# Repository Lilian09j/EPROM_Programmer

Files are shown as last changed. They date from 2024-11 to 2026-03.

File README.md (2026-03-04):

# EPROM_Programmer
EPROM programmer (reading and writing operations) for 27C512 and 27C64 UV and EEPROMs.

Provide a manual programmation through Dip switchs as well as a microprogrammed one based on a STM32F103. A MAX734 is used to generate the 12v tension needed for programming. PCB conception made on Altium Designer. A JAVA app were developed to communicate buy USB with the PIC microcontroller allowing reading and programming.

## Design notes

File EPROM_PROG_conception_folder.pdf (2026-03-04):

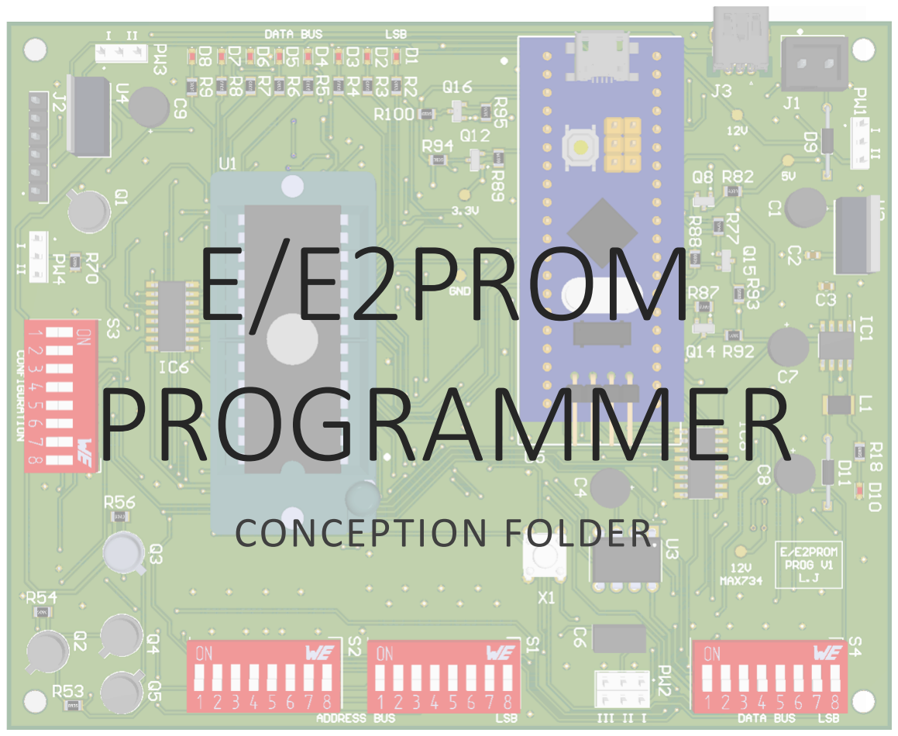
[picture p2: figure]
E/E2PROM PROGRAMMER; CONCEPTION FOLDER

E/E2PROM PROGRAMMER | 1 | L.J
JAOUANNE Lilian | 07-2025

E/E2PROM PROGRAMMER | 2 | L.J

## Table des matières

E/E2PROM PROGRAMMER | 3 | L.J

## Introduction

The E/E2PROM PROG board is used to read and program UV-EPROM (Erasable Programmable Read-Only Memory) and (Electrical Erasable) EEPROM non volatile memories with a maximum of 64kB.
The memory bytes can be read or written either manually via DIP switches (manual mode) or through a Java-based GUI application running on a laptop. The application communicates with the STM32F103 microcontroller on the board via USB, which operates as a Virtual COM Port (VCP). Mode selection is done using jumpers on the board.

The EPROM component must be in an FDIP28 (28 pin Ceramic Frit-seal DIP) or FDIP28W package, with FDIP28W indicating the presence of a quartz window on top of the case, which allows the memory to be erased using ultraviolet (UV) light.

When delivered (and after each erasure for UV EPROM), all bits of the M27C512 are in the '1' state. Data is introduced by selectively programming '0's into the desired bit locations. Although only '0's will be programmed, both '1's and '0's can be present in the data word. The only way to change a '0' to a '1' is by die exposure to ultraviolet light (UV EPROM).
The M27C512 begins to erase when exposed to light with wavelengths below 400 nm (4000 Å
- angstrom). Direct sunlight can cause erasure in about one week. The recommended method is UV-C exposure at 2537 Å (253.7 nm) for faster, controlled erasure.

The integrated dose (i.e. UV intensity × exposure time) for erasure should be a minimum of 15 W. sec. cm² or J. cm⁻²
e.g. : Erasure time of 20min using an UV lamp with 12000µW. cm⁻² power rating.
- The UV-EPROM 27C512 (512 kbits) has 16 addresses bits so 2

16 = 65536
addressable 8-bit memory area.

2

16 × 8bits = 2

16 × 2

−10 × 8kbits = 2

6 × 2

3kbits = 512kbis = 64kB

Thus, the memory can be represented by 4096 (2

16/16) lines of 16 bytes. The range of addresses of the lines would be 0x0000 to 0xFFF0 (2

16 − 16 bytes) as well the last address byte is 0xFFFF.

- However the EEPROM 28C64 (64 kbits) has only a 13 addresses bits so 2

13 = 8192
addressable 8-bit memory area.

2

13 × 8bits = 2

13 × 2

−10 × 8kbits = 2

3 × 2

3kbits = 64kbis = 8kB

Thus, the memory can be represented by 512 (2

13/16) lines of 16 bytes. The range of addresses of the lines would be 0x000 to 0x1F0 (2

13 − 16 bytes) as well the last address byte is 0x1FF.

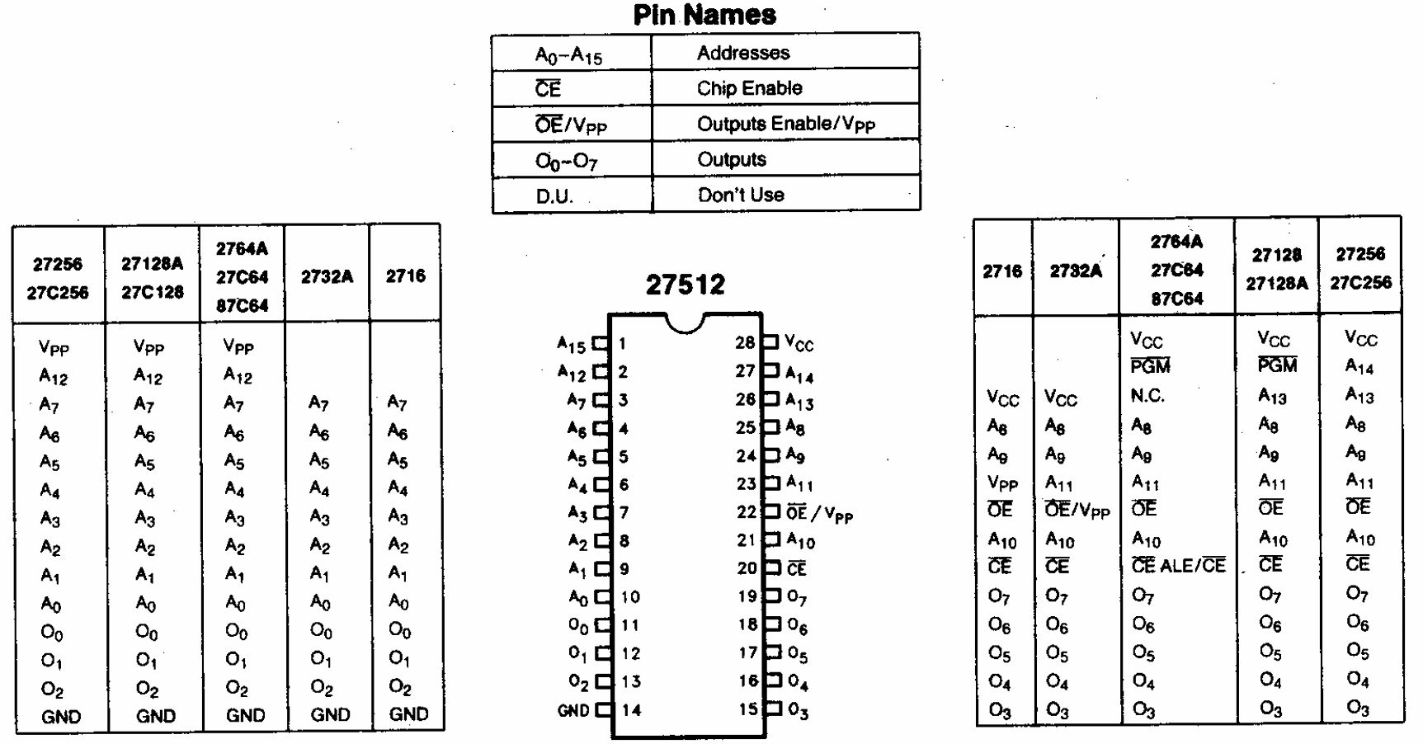
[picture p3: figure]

E/E2PROM PROGRAMMER | 4 | L.J

## I. EPROM mode details

## Pinout

The 28C64 EEPROM’s pinout has some differences with the 27C512 one :

A13 : NC, A14 : PGM also called write enable WE for 28C64, A15 : Ready/Busy Output 10K resistor as A15 can be an output (28C64) or an input (27C512).

Figure 1 : 27C512 – 27C64 pinout

The modes of operations of the 27C512 are listed in the Operating Modes table (Cf. Table 1). All inputs are TTL levels except for OE/Vpp and 12v on A9 for Electronic Signature.

Table 1 : 27C512 operating modes
Mode | Vcc | CE | OE/Vpp | A9 | Q7 − Q0
Read | 5v | VIL | VIL | X | Data Out
Output disable | 5v | VIL | VIH | X | Hi-Z
Program | 6v | VIL pulse | Vpp | X | Data In
Verify | 6v | VIL | VIL | X | Data Out
Program Inhibit | 6v | VIL | Vpp | X | Hi-Z
Standby | 5v | VIH | X | X | Hi-Z
Electronic Signature | 5v | VIL | VIL | VID | Codes IDs

X = VIH (5v) or VIL(0v) , Vpp = 12,75v ± 0,25v (if M27C512) , Vpp = 12,5v ± 0,5v (if D27C512), VID = 12v ± 0,5v

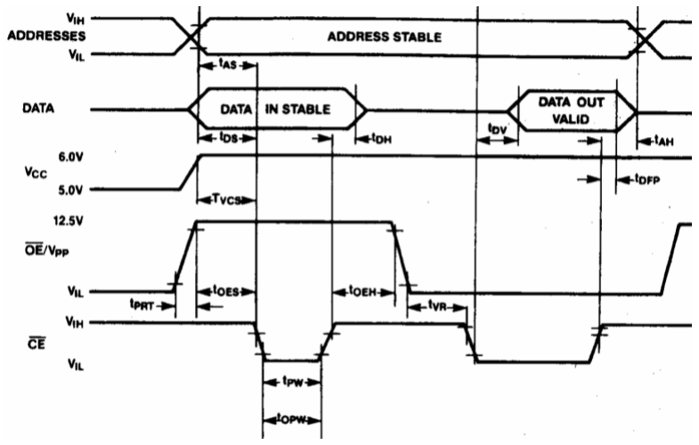
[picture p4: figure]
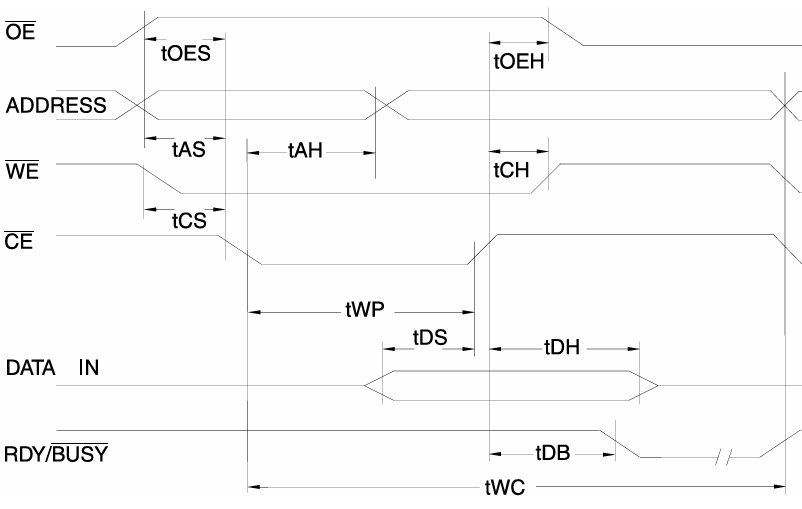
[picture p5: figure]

E/E2PROM PROGRAMMER | 5 | L.J

However after tests the writing mode is still working with Vpp under 12v. As well we can take it after the diode in series with the 12v source.

## Reading mode

The 27C512 has 2 control functions, both of which must be logically active in order to obtain data at the outputs. Chip Enable (CE) is the power control and should be used for device selection. Output Enable (OE/Vpp) is the output control and should be used to gate data from the output pins, independent of device selection.

## Writing/programming mode

Figure 2 : EPROM (D27C512) programming waveform | Figure 3 : EPROM (28C64) programming waveform \C\E controlled

The time characteristics are provided in the datasheets.

A verify (read) should be performed on the programmed bits to determine that they have been correctly programmed. The verify is performed with OE/Vpp and CE at VIL and Vcc is at its programming voltage (6v).

The 28C64’s pin 1 is READY/BUSY (not A15 as for the 27C512). It has an open drain output that can be used to detect the end of a write cycle. READY/BUSY is actively pulled low during the write cycle and is released at the completion of the write. The open drain connection allows for OR-tying of several devices to the same READY/BUSY line.

Remark : The READY/BUSY is not connected for the AT28C64X.

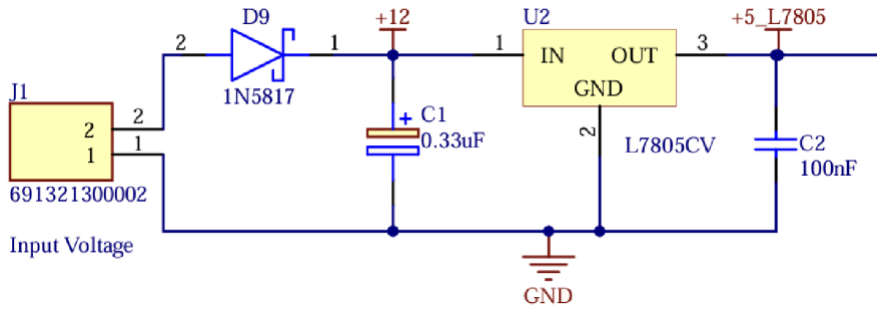
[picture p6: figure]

E/E2PROM PROGRAMMER | 6 | L.J

## II. Board power supply

The board requires a 12v power supply. This 12v generates a 5v voltage by a linear regulation. The L7805CV is a three-terminal 5v positive regulators in a TO-220 package. It can provide a maximum output current of 1,5A.

Power Dissipation Without Heatsink :

TJmax = 125°C (junction temperature, temperature inside the silicon die of the chip)

RθJA = 65°C/W (thermal resistance from junction to ambient)

Pmax =

TJmax − Tambient

RθJA

=

125 − 25
65 ≈ 1,54W

Thus, without a heatsink, the L7805CV can safely dissipate 1,5W.

The input decoupling capacitor C1 stabilizes the input voltage, especially if it is noisy or coming from a long wire or switch-mode supply to prevents oscillations in the regulator. It is required if the regulator is located far from the power source.

The output decoupling capacitor C2 improves the transient response, high-frequency noise and helps smooth out voltage changes due to load variations.

A Schottky diode (metal-semiconductor junction) in series with the input is used to block reverse voltage, preventing damage. It has a lower forward voltage drop: ~0.3 − 0.4 V (vs. ~0.7 V for standard diodes in Silicon with an PN junction).

Remark : Even if the L7805 can accept an input until 35v, the input voltage must be 12v ± 0,5v in this application, as the 12v source is also used for the EPROM OE for programming purposes.

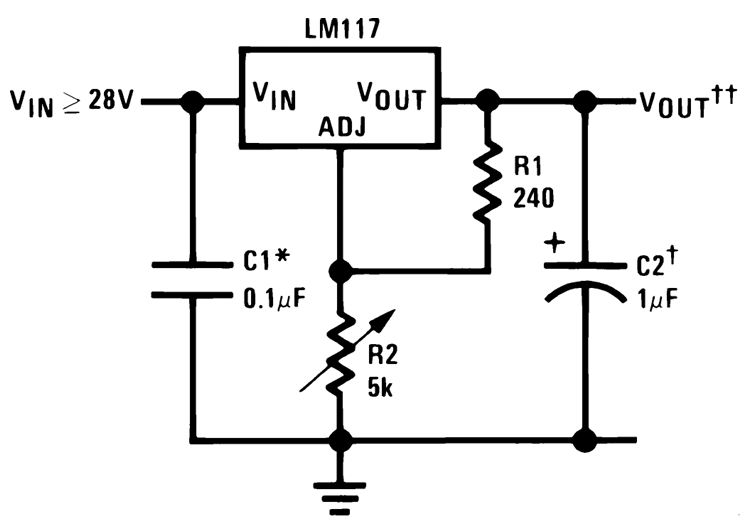
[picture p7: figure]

E/E2PROM PROGRAMMER | 7 | L.J

## III. EPROM 5v/6v power supply

The EPROM requires a 5v power supply in reading mode and 6v in writing on the pin Vcc (28).

Figure 4 : LM317 basic schematic from datasheet
Computing the output voltage (Vout) of an LM317 1.2-37v adjustable regulator (from an input at least 3v over the desired output) is done using the following formula (Eq. XIII.1) :

Vout = 1.25 × (1 +

R2
R1

)

R1 and R2 are the values of the trimmer resistors. In practice, one usually chooses a value for R1 (often 220 or 240 ohms) and calculates the value of R2 needed to obtain the desired output voltage.

The LM317's internal reference voltage is 1.25V. This voltage is always present between the ADJ pin and the OUT pin.

- Vout = 6v with R1 = 220Ω :
R2 = (
Vout

Vref

− 1) × R1 =
6 − 1,25
1,25 × 220 = 830Ω (we will take R2 = 820Ω)

R2 × IADJ ≈ 820 × 50.10⁻⁶ = 4,1mV (negligible)

- Vout = 5v with R1 = 220Ω :

R2 =

5 − 1,25
1,25 × 220 = 660Ω

Let R2 and R3 be 2 resistors in parallel, we want R3 such as Req ≈ 660Ω.

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
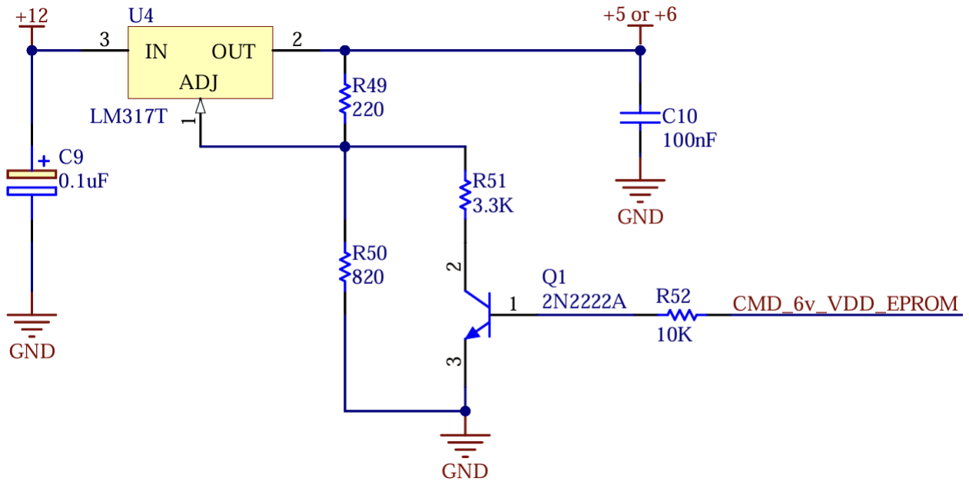
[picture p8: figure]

E/E2PROM PROGRAMMER | 8 | L.J

R3 =

Req × R2
R2 − Req

=

660 × 820
820 − 660 ≈ 3,38kΩ (we will take R3 = 3, 3kΩ)

Figure 5 : 5 or 6v regulation diagram with LM317 for EPROM power supply

- NPN Q1 transistor blocked if CMD_6v_VDD_EPROM Low : Vout ≈ 1,25 (1 +

820
220) = 5,91v
- NPN Q1 transistor passing (saturated) if CMD_6v_VDD_EPROM High :

Req =

820 × 3,3.10³
820 + 3,3.10³

≈ 657Ω

Vout ≈ 1,25 (1 +

657
220) = 4,98v

Remark : The power switching characteristics of Advanced CMOS EPROMs require careful decoupling of the devices. The supply current ICC has three segments that are of interest to the system designer: the standby current level, the active current level, and transient current peaks that are produced by the falling and rising edges of CE. The magnitude of the transient current peaks is dependent on the capacitive and inductive loading of the device at the output. The associated transient voltage peaks can be suppressed by complying with the two line output control and by properly selected decoupling capacitors. It is recommended that a 0,1µF ceramic capacitor be used on every device between VCC and VSS. This should be a high frequency capacitor of low inherent inductance and should be placed as close to the device as possible.

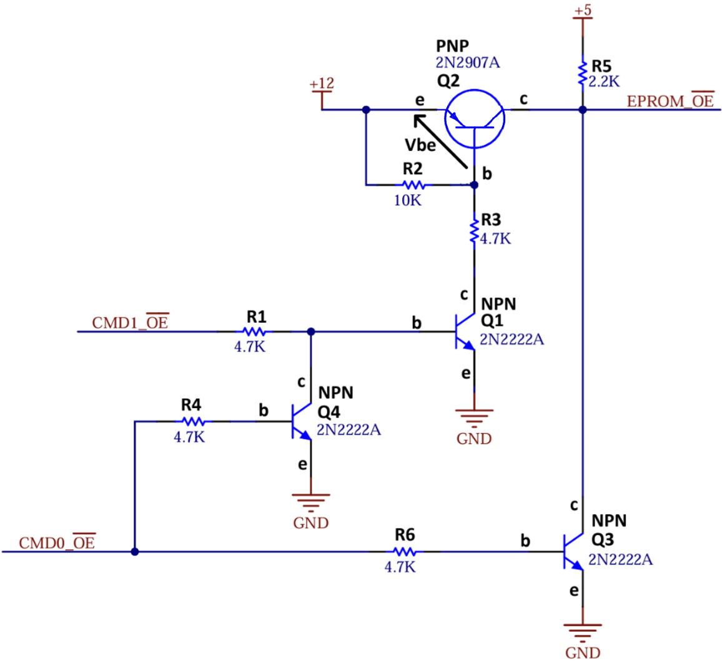
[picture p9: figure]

E/E2PROM PROGRAMMER | 9 | L.J

## IV. 3 States EPROM \O\E (0, 5, 12v)

The EPROM OE̅̅̅̅ pin can take 3 states :

- 0v if reading (OE active)
- 5v if (OE disabled)
- 12v (Vpp) if writing (only for UV-EPROM 27C512)

A Mux4->1 could have been used but the CMOS technology can support a maximum of 6v on its inputs.

Figure 6 : Scheme command 3 state EPROM \O\E

Table 2 : EPROM_\O\E voltage depending on the 2 logic commands
CMD1 CMD0 | 0v | 5v
0v | 5v | 12v
5v | 0v | 0v
- CMD0 at high :
Q3 is saturated so the output is put to the ground through Q3, the output voltage will be ε = Vce(Q3)~0v if well saturated.

E/E2PROM PROGRAMMER | 10 | L.J
- CMD0 at low and CMD1 at low :
CMD0 at low block the bipolar transistors Q3 and Q4. CMD1 low too, Q1 is blocked, the base of Q2 becomes at the same 12v potential than its emitter. Vbe(Q2

) = 0 >
−0,6v so being a PNP, Q2 is blocked too. The output will be linked with the 5v source through R5. Else if is no longer connected to ground
- CMD0 at low and CMD1 at high :
This time Q1 is saturated and the divisor bridge R2 R3 will make the potential of the base of Q2 lower than the 12v source at the emitter. Vbe(Q2

) = Vb − Ve < −0,6v
so Q2 is saturated. The output voltage will be 12v − ε, where ε = Vce(Q2)~0v.

All the transistor’s emitters are put to a fixe potential.

Resistor choices :
Q1 saturated provide the current to R3 : VR3 = 12 − Vbe(Q2

) − Vce(Q2

) ≈ 11,4v
Vce(Q2

)~0v and Vbe(Q2

) ≈ 0,6v(diode voltage)

IR3 =

11,4
4,7.10³

≈ 2,4mA

We consider an HFE gain of 10 for Q1 in saturated mode (Vce as low as possible).

IR1 =

2,4.10⁻³
10 = 0,24mA

CMD0 and CMD1 logic 5v TTL : VR1 = 5v − Vbe(Q1) = 5 − 0,6 = 4,4v

R1 =

VR1
IR3
= | 4,4
2,4.10⁻⁴
| ≈ 18k

So, to saturate Q1, we need R1 < 18k. Idem for Q3 and Q4.

The EPROM OE̅̅̅̅ input impedance being high, the current consumed will be really small and so the output voltage drop in R5 will be small.

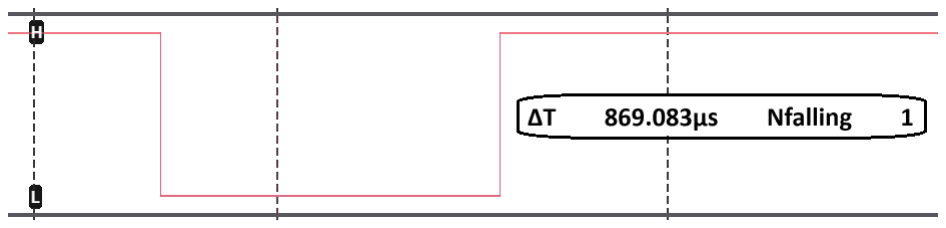
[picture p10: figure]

E/E2PROM PROGRAMMER | 11 | L.J

## V. EPROM \C\E TTL Low-level pulse

To write the data byte at a specific address, a TTL low-level pulse must be applied to the CE input with OE/Vpp at its programming voltage and Vcc at 6v.

The tPW low pulse time differs between EPROM corresponding to the CE initial program pulse width :

Table 3 : UV-EPROM and EEPROM Low pulse times
E/E2PROM | Min tPW | Typ tPW | Max tPW | Unit
D27C512 (Intel UV-EPROM) | 0,95 | 1,0 | 1,05 | ms
28C64 (EEPROM) | 0,1 | − | 1 | μs
M27C512 (STMicroelectronics UV-EPROM) | 95 | − | 105 | μs

Remark : The M27C512 program pulse width is not performed in hardware on the PCB.
We want to generate the low pulse on the pressing of a push button (or switch), however it will generate bounds and it’s impossible to make it exactly 1ms.
So, by pressing the push button we will connect the negative borne of a capacitor to the ground. As the capacitor is initially charged and connected to the 5v power supply through R3, the capacitor will charge. C1 and R3 are an RC filter with a time characteristic equal to R × C.

By default the capacitor is not charged and not connected to the ground, only its positive borne is at 5v and directly connected to AOP’s non inverting input v

+. Then, the voltage of
the AOP’s inverting input v

− from the divider bridge (~1,7v) is lower than voltage on the non inverting input (v

+ > v

−). In that case the CE (connected to the AOP’s output) would be Vcc

+
so 5v.
Once the button is pressed, v

+ will change to 0v as the uncharged capacitor will no be connected to the ground. When the charge of C1 will reach the voltage of v

−, so the output
will change back to 5v.
Once the button released, the capacitor will discharged through R4 and R3.

Figure 7 : Experimental low pulse time measured with a logic analyser

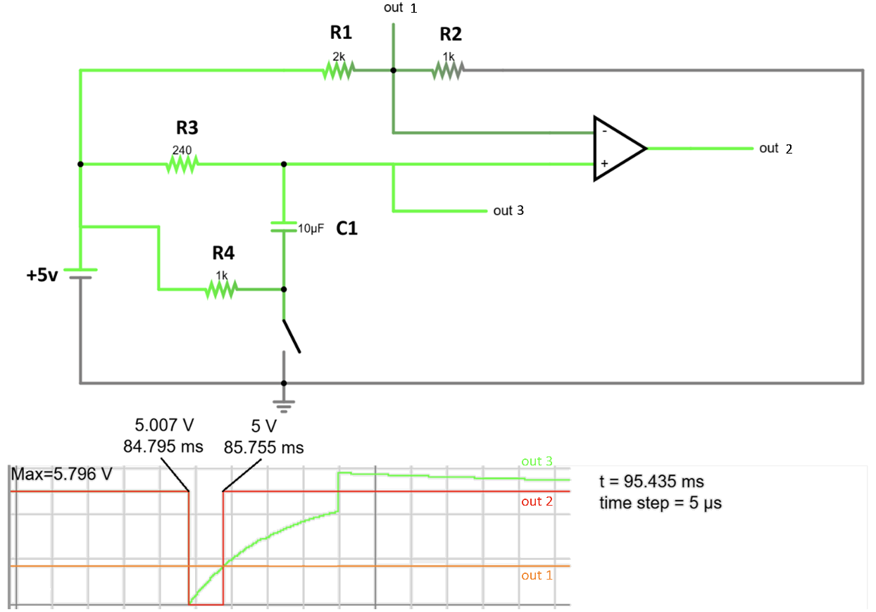
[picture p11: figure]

E/E2PROM PROGRAMMER | 12 | L.J

Figure 8 : Falstad low pulse simulation

Vs = Vcc (1 − e
−

t
τ) (Eq. XIII.2)
- Finding R3 and C1for UV-EPROM 27C512 :

Vs = Vcc (1 − e
−

t

τ) , we are looking for τ sucℎ as { Vs = 5/3 ≈ 1,7v (v

−)
Vcc = 5v
t = 1ms (tPW 27C512)

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
= ln (1 −

Vs

Vcc

)

τ =

−t
ln (1 −

Vs
Vcc

)

Analytic application :

τ =

−10⁻³
ln (1 −

5/3
5

)

=

−10⁻³
ln (1 −

1/3)

=

−10⁻³
ln (

2/3)

=

−10⁻³
ln(2) − ln(3)

≈ 2, 47ms

Furthermore the time constant τ = R3C1, we fixe C1 = 10μF :

R3 =

τ
C1

=

2,41.10⁻³
10⁻⁵ = 241 (we take R3 = 240Ω)
- Finding R3 and C1for EEPROM 28C64 :

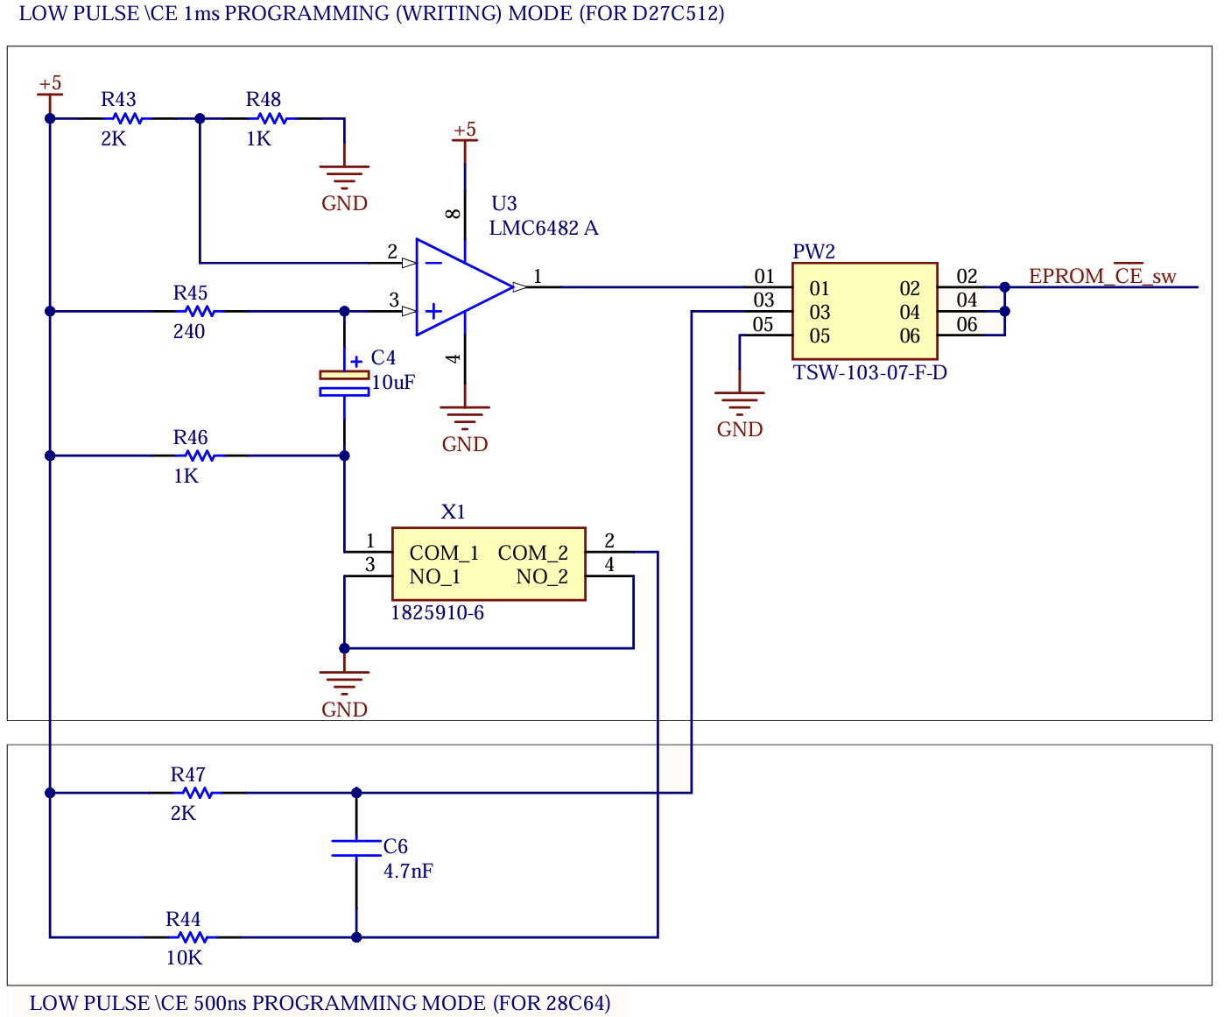
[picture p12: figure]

E/E2PROM PROGRAMMER | 13 | L.J

The low pulse time for the EEPROM being really short and as it can be over a pretty big range of time values, we don’t compare the RC filter voltage using an AOP as done for the UV-EPROM. The minimum EPROM threshold detection for an high voltage input is VIH = 2v. The time taking by the discharged capacitor to become 2v charged need to be between 0,1 and 1μs.
Its working with C1 = 4,7nF and R3 = 2kΩ.

Remark : The value of the discharge resistor R4 will impact the peak and the discharge time after realising the push button. R4 was chosen by testing.

Figure 9 : Both low pulses generated by one push button

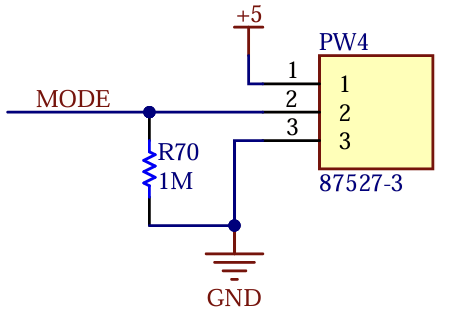
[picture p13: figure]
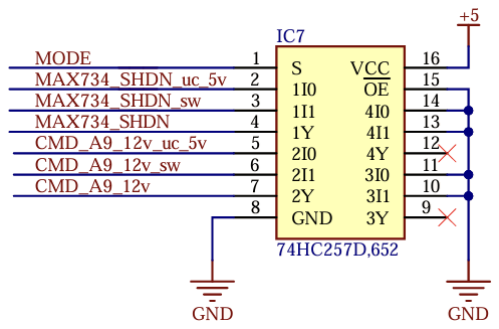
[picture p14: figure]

E/E2PROM PROGRAMMER | 14 | L.J

## VI. Manual and MCU command selection

3 Pins allow the user to select the mode, either for a manual programming one (through dip switchs) either by the STM32.

Mode | Jumper
Manual | 1-2 (I)
MCU | 2-3 (II)

Figure 10 : Mode selection by jumper

As an example, 74HC257 (3 output states Quad Mux 2 to 1) are use to select command signals (TTL) among one from dip switch and an other one from an STM32 pin after a level shifter to 5v.
e.g. : If the MODE signal is set at 5v (manual programming)so the multiplexer command input is set to high, it’s the input I0 that will be rewrite to the Y output.

Figure 11 : 3 Output states Quad Mux2->1 for EPROM configuration (selection with MODE)
If the OE is set to high, so all the four Y outputs would be in high impedance state (Z-state). In this application, its not needed to set them to high impedance as the Mux’s outputs are always enabled (OE connected to the ground), thus a 2 state one (74HC157) would have convinced.

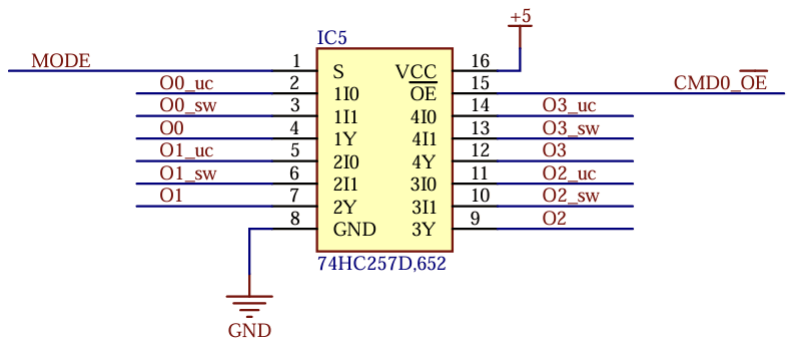
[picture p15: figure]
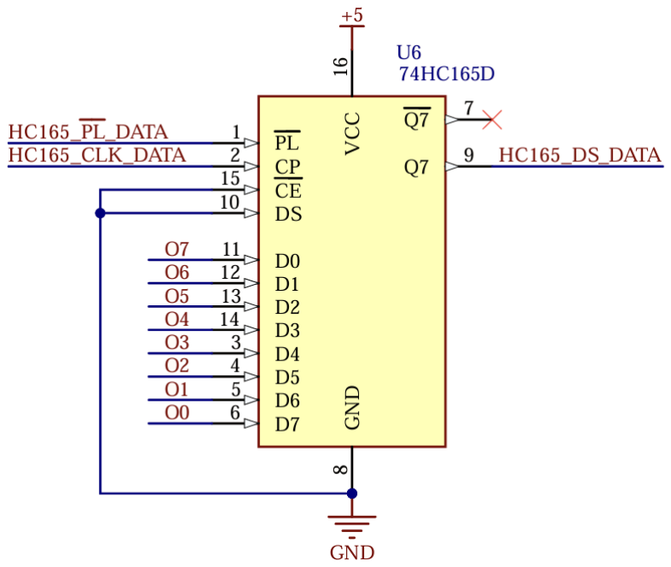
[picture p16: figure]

E/E2PROM PROGRAMMER | 15 | L.J

## VII. Shift registers

The 8-bit data bus can function as outputs during memory read operations, or as inputs during programming. The bit to be written can originate either from the STM32 (via the output of a PISO shift register, used to extend its output pins) or from a DIP switch for manual programming.

Both sources feed into a 3-state 2-to-1 multiplexer (74HC257). The control signal CMD0 is set high (5v) during memory read operations. In this case, the multiplexer’s OE (Output Enable) pin is also high, placing all outputs in a high-impedance state to avoid bus contention or short circuits. Conversely, when CMD0 is low, indicating a programming operation, the multiplexer outputs are enabled, allowing the selected input source (either the shift register or the DIP switch) to drive the data bus.

Figure 12 : Quad 3 states mux2->1 for pin data bus selections

## Parallel inputs - serial output (for reading)

The 74HC165 is an 8-bit shift
register with complementary outputs from
the last stage.
Data can be loaded into the register either in parallel or serially. When the Shift/Load ( SH/PL , pin 1) input is low, the 8-bit parallel data on inputs D0–D7 is loaded
asynchronously | into | the | register.
When SH/PL is high, the register enters shift mode : its contents shift right on each rising clock edge, and new data is shifted in through the serial input (SER or DS, pin 10).
In this setup, the SER pin is tied to ground,
since only a single shift register is used and
no additional serial input data is needed. | Figure 13 : 74HC165 8-bits shift register - parallel inputs / serial output

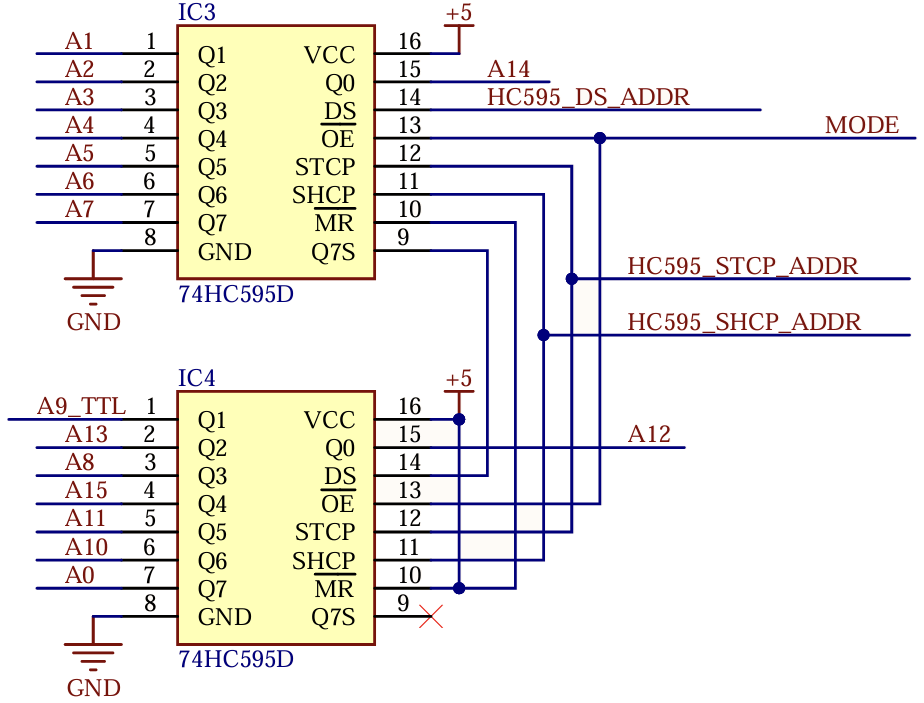
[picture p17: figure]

E/E2PROM PROGRAMMER | 16 | L.J

Remark : The parallel load (PL) and clock signal are STM32 outputs translated to 5v logic by BSS138 N-channel MOSFETs. The serial output (Q7) is also translated to 3,3v logic before arriving on the STM32 input.

## Serial input - parallel outputs (for writing)

A 74HC595 shift register is used to write the 8-bit data bus. Its OE pin is tied to ground, keeping its outputs always active, as they are directly connected to the previously discussed multiplexer.

Two additional 74HC595 chips are connected in series to write the 16-bit address bus (2 bytes). These shift registers have tri-state outputs, entering high-impedance (Z) state when their \OE pin is high. This occurs when the 'mode' signal is high, allowing the STM32 to release control of the address bus during manual programming via DIP switches.
To prevent conflicts or damage, 100kΩ series resistors are added after each DIP switch line. These protect the lines in cases where the shift register outputs are active (not in Z-state) while the MCU is writing an address (when 'mode' is low).

Two 74HC595 shift registers can be chained by connecting the Q7S output of the first to the DS input of the second, allowing 16 bits to be shifted in serially.
Each rising edge on SHCP shifts a bit into the register. The first bit (MSB) goes to Q7 of the second register, while the last bit (LSB) ends up at Q0 of the first. A rising edge on STCP then latches the full 16-bit value to the outputs.

Figure 14 : 2 74HC595 8-bits shift register - serial input / parallel outputs

E/E2PROM PROGRAMMER | 17 | L.J

Remark : The bit order of the shift register’s outputs has been rearranged to simplify the routing of the board

## VIII. Identify E/E2PROM

To activate the intelligent identifier mode, the board must force 11,5v to 12,5v on address line A9 of the EPROM. In order to identify the chip (device and manufacturer) with the 5v voltage from the USB VBUS only, a MAX734 is used to boost the voltage until 12v.

The part number M27C512 breaks down as follows: M stands for Memory, 27 indicates the EPROM family, C refers to CMOS technology (if not specified the technology is HMOS. The prefix M is used by STMicroelectronics, D by Intel and AT by Atmel, the chips are functionally and electrically equivalent, however they have different manufacturer and device’s codes.

- For the UV-EPROMs (27 family), two identifier bytes may then be sequenced from the device outputs by toggling address line A0 from VIL to VIH. All other address lines must be held at VIL during this mode except for A14 and A15 which should be held high for the D27C512 only.

Table 4 : Electronic signature for UV-EPROMs (27 family)
Pins
Identifier | A0 | O7 | O6 | O5 | O4 | O3 | O2 | O1 | O0 | Hex data

Manufacturer's code
STMicroelectronics | VIL | 0 | 0 | 1 | 0 | 0 | 0 | 0 | 0 | 0x20
Intel | VIL | 1 | 0 | 0 | 0 | 1 | 0 | 0 | 1 | 0x89
Device code
D27C256 | VIH | 1 | 0 | 0 | 0 | 1 | 1 | 0 | 1 | 0x8D
D2764A | VIH | 0 | 0 | 0 | 0 | 1 | 0 | 0 | 0 | 0x08
D27256 | VIH | 0 | 0 | 0 | 0 | 1 | 0 | 0 | 0 | 0x04
D27C512 | VIH | 0 | 0 | 0 | 0 | 1 | 1 | 0 | 1 | 0x0D
M27C512 | VIH | 0 | 0 | 1 | 1 | 1 | 1 | 0 | 1 | 0x3D
- For the EEPROMs (28 family) an extra 32 bytes of EEPROM memory are available to the user for device identification. By raising A9 to 12 ± 0.5v and using address locations 0x1FE0H to 0x1FFFH the additional bytes may be written to or read from in the same manner as the regular memory array. Nothing is previously written by the manufacturer to identify the chip.

The MAX734 is a current-mode PWM controller used in a boost converter to step up voltages, such as converting +5v to +12v. It uses two feedback loops: an inner loop for cycle-by-cycle current limiting, and an outer loop to regulate the output voltage via an error amplifier. If more current than the maximum rated load is drawn, the output voltage drops,

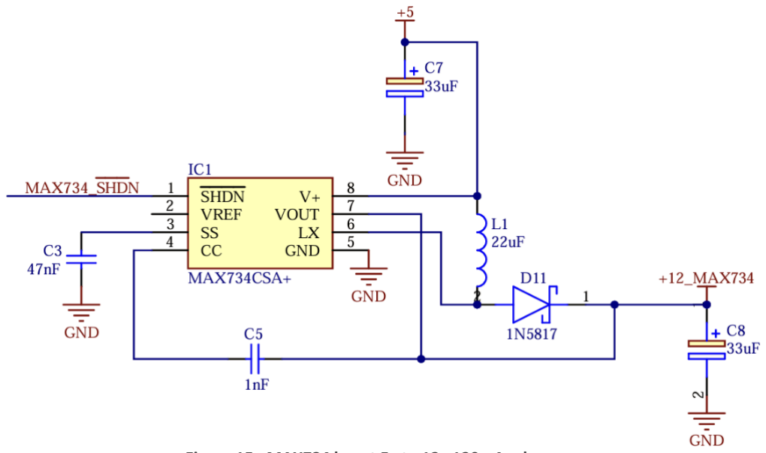
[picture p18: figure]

E/E2PROM PROGRAMMER | 18 | L.J

and the overcurrent comparator trips around 1,5A. In normal operation, the external FET (Field-Effect Transistor) switches energy through an inductor, which is released to the output through a diode. When the SHDN pin is held low, the regulator enters shutdown mode, disabling the FET but still allowing current flow from V+ to the load through the passive inductor-diode path.

Table 5 : MAX734 pin functions

SHDN | Shutdown – active low. Power switching FET is held off when SHDN is low.
VREF | Reference Voltage Output (+1,23v) – supplies up to 100μA for external loads
SS | Soft-Start. Capacitor between SS and GND provides soft-start and short-circuit protection
CC | Compensation Capacitor Input. Externally compensates the outer feedback loop.
LX | Drain of internal N-Channel power MOSFET
Vout | Output-Voltage Sense Input. Provides regulation feedback sensing.

Figure 15 : MAX734 boost 5v to 12v 120mA scheme
The 12v 120mA output is sufficient only for EPROM’s A9 pin (read memory's manufacturer information). Tests showed than the 12v generated collapses if sent to EPROM OE pin to programme the memory.

Remark : A MAX732 could have been usued to generate the 12v and to handle currents untli 250mA.

For normal addressing the A9 address pin can be at 0v or 5v (TLL levels), however for device identification it needs to be put at 12v (generated by the MAX734).

An analog switch (DG419) is used to select and send to the A9 pin the voltage among the 12v and the A9_TTL from the dip switch or STM32 that can be either 0v or 5v.

The DG419 acts like a digital-controlled analog signal switch that operates with supplies from ±5v to ±15v. It connects one of two inputs (S1 or S2) to a common line (D) based on a control

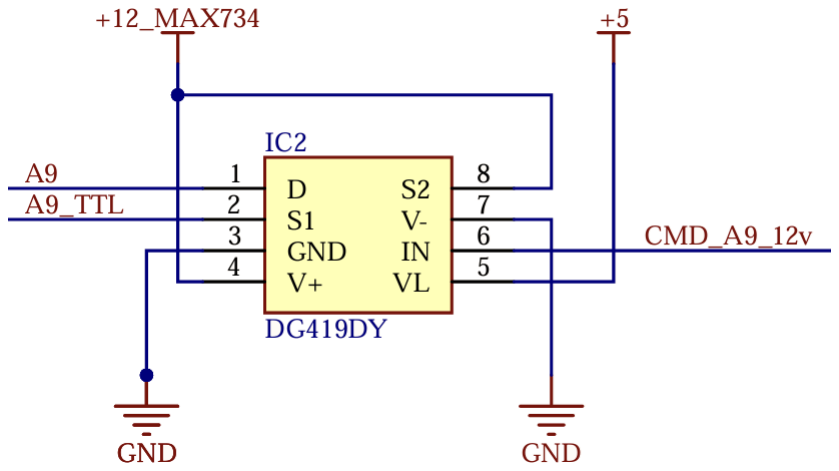
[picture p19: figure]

E/E2PROM PROGRAMMER | 19 | L.J

pin, and works for both analog and digital signals. The VL pin of the DG419 stands for logic level positive supply input.

IN input | S1 | S2
Logic 0 (IN = 0v) | ON | OFF
Logic 1 (IN = VL) | OFF | ON

Figure 16 : Analog switch selection for A9 pin 0-5-12v

If MAX734’s SHDN pin is at 0v so output voltage is at 5v (the DG419 can still commute on 5v or 0v form A9 (not 12v)).

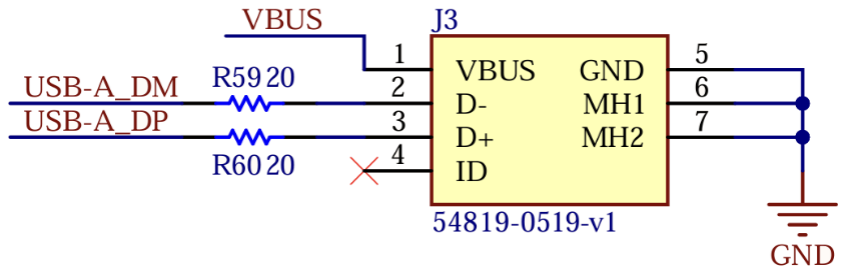
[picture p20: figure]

E/E2PROM PROGRAMMER | 20 | L.J

## IX. STM32 Microcontroller

## USB Communication

A connector USB mini is used to exchange data between the STM32F103C8T6A present on the blue pill board and the Graphical User Interface (GUI), app launched on a laptop. The 2 pins of data DM and DP are respectively connected with the STM32 blue pill’s pins PA11 and PA12. Those two pins are also those used by the USB micro soldered on the blue pill board (thus both connectors can be used).
DM (D–) and DP (D+) are the differential data lines used for communication in USB connections. They carry signals as a differential pair to reduce noise and improve data integrity.
Remark : For proper signal timing and to avoid data errors, DM and DP should have the same wire length. Unequal lengths can cause signal skew, leading to degraded performance or communication failure. Matching their lengths ensures reliable high-speed data transmission.

Figure 17 : USB mini connector
The identification pin ID is let Not Connected (NC) for the laptop to know that the board is a peripheric. The VBUS is a 5v supply provided by the laptop. It is delivered through the connected USB port.
The communication uses the USB CDC protocol (Communication Device Class). The STM32 acts as a Virtual COM Port (VCP), which is a Windows interface for accessing serial communication over USB. We configure the STM32's hardware USB peripheral to operate as a CDC device, allowing it to connect to a VCP on the PC. This setup enables data exchange over USB at full-speed (12 Mbps).

## BSS138 Voltage translation

IC (integrated circuit) based on HC technology (High-speed CMOS) such as the 74HC165 and 74HC595 shift registers on the board have an high-level input voltage VIH minimum threshold of 3,15v for Vcc = 4.5v and 4,2v for Vcc = 6v.
However as the STM32 logic is 3,3v, voltage translators are required to adapt the voltage levels.

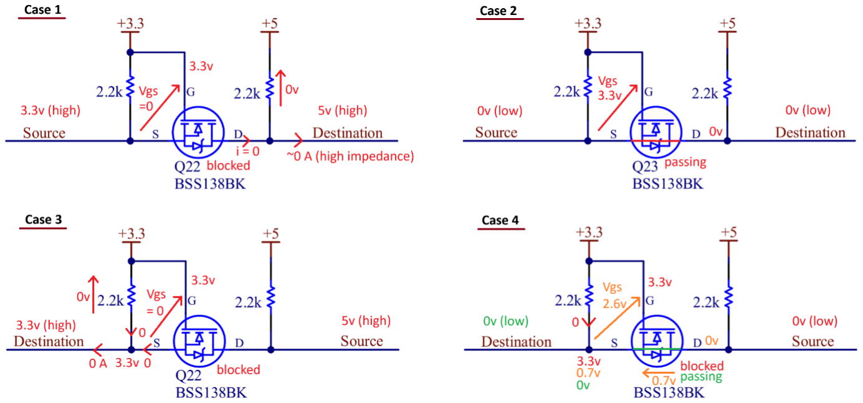
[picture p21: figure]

E/E2PROM PROGRAMMER | 21 | L.J

The BSS138 is a low-voltage N-channel MOSFET commonly used for bidirectional voltage level translation. The voltage translation is realised by using one BSS138 and two pull-up resistors per signal line.
The BSS138 turns on fully with a low gate-source voltage VGSTH ≈ 1,3v. The transistor is passing if VGS > VGSTH.

RDSON = 1Ω (Static Drain Source On resistance) for VGS = 4,5v and ID = 0,22A

Remark : The CMOS can works with a Vcc = 2v and in that case the minimum threshold for VIH would be 1,5v what would be compatible with the STM32 logic levels. However, the EPROM 5v logic impose to have a regulation.

Four situations are possible as the source can come from the 3,3v as from the 5v and the source can be at high or low state.

Figure 18 : Bidirectional voltage translation explanation

- Case 1 : 3.3v source – high state
The gate source voltage of the N-channel MOSFET is zero (VGS = VG − VS = 0v).
VGS = 0v < VGSTH = 1,3v, the transistor is blocked. The component connected to 5v source has an high impedance so a small current. As there is no current going in the 5v pull-up resistance, the tension across its terminals is zero and the 5v goes to the destination signal.
- Case 2 : 3.3v source – low state
VGS = 3.3v > VGSTH = 1,3v, the transistor is saturated so passing. The 0v at the source is copied to the drain.
- Case 3 : 5v source – high state

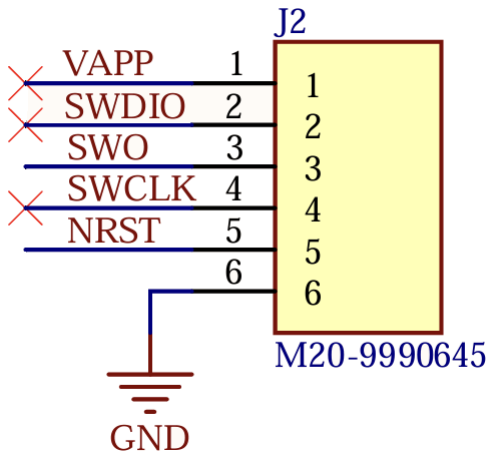
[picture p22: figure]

E/E2PROM PROGRAMMER | 22 | L.J

The 3,3v signal is now an input so the 3,3v source will be linked to the signal as almost no current is crossing the resistor.

- Case 4 : 5v source – low state
Initially there is no current in the 3,3v pull-up resistance so the source voltage is 3,3v.
VGS = 0v < VGSTH = 1,3v, the transistor blocked.

However, as the voltage across the internal diode is over its 0,7v junction voltage the current can pass from the source to the gate through the diode and the voltage of the source is reduced to 0,7v (VDrain + 0,7v), that is a transitional state.
Thus the gate source voltage becomes VGS = 3,3 − 0,7v = 2,6v > VGSTH = 1,3v , the transistor is saturated and the 0v of the source go to the destination signal.

For example, BSS138 MOSFETs are used to level-shift the STM32's 3,3v control signals to the 5v logic level required by the 74HC165 parallel-in serial-out (PISO) shift register, and to safely receive its serial output back at 3,3v.

## Debug

On genuine ST-Link V2 debug probe, VAPP (pin 1 and 2) is only an input. It is used to sense the target voltage. It does not supply power, but instead allows the debugger to adapt its I/O voltage levels (typically between 1.8 V and 3.3 V) to match those of the target microcontroller. The STM32 should be powered on by an other external source to process the flashing/debug. However on many ST-Link V2 clones, the VAPP pin is connected directly to 3.3V from the USB regulator inside
the dongle, and therefore acts as a power output. In that
case the STM32 can be flashed with the VAPP 3.3v output.
The current provided by the probe might not go over 100mA which might not be enough to ensure the proper functioning of the whole PCB board
The pin SWO of the probe is connected through the main board to the pin PB3 of the STM32, likewise NRST is connected on the blue pill NRST pin.
However the 3 other pins VAPP, SWDIO and SWCLK must be connected on the blue pill SWD port.

Remark : The blue pill can be blocked if flashed without Serial Wire enabled (SYS/Debug in SMT32CubeIDE IOC file). To solve it both boot jumpers (BOOT0 and BOOT1) must be set on ‘1’, the reset button should then be pressed. Depower the board and put back the 2 boot jumpers on ‘0’. The board can now be connected with STM32CubeProgrammer through the debug probe STLink-v2 (SWD port). The full chip memory need to be erased and disconnected.

Figure 19 : SWD debug port

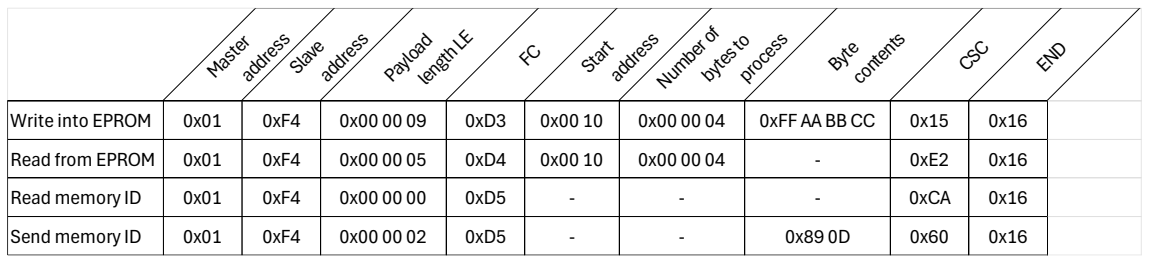
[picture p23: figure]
Master; address Slave; address; Payload; length LE; Start; Number of bytes to; process; Byte; contents; CSC; END

E/E2PROM PROGRAMMER | 23 | L.J

## X. Communication protocol with GUI

## GUI request frame

Table 6 : Communication protocol - GUI read/write request frames

The master address correspond to the address of the sender, it is either ‘0x01’ for the GUI (Java application) either ‘0xF4’ for the STM32 in the board with the EPROM. Conversely, slave address is the receiver’s address.

The 3 bytes of payload length (LE) corresponds at the plaintext’s number of bytes (from the start address index to the last byte content index).

e.g. : LE = 2 + 3 +Number of bytes to process = 0x(2 +3 + 4) = 0x9

e.g. : Number of bytes to process = 0x00 1A FF. Thus, LE = 0x(2 + 3 +1AFF) = 0x1B04

The function code (FC) is equal to ‘0xD3’ for a writing into memory request, ‘0xD4’ for a reading one and ‘0xD5’ for requesting the 2 EPROM identification bytes.

Then, the frame contains 2 bytes to specify the start address. Address at which we will start to write the byte contents (if FC = ‘0xD3’) or read the EPROM memory content (if FC = ‘0xD4’). A field a 3 bytes contains the number of bytes to process (to write or read) depending on the function code.
The byte contents field is only present with the function code ‘0xD3’ for a request or with function code ‘0xD4’ for an answer to a reading request. The byte content MSB (most significant byte) corresponds to the byte stored (or to be stored) at the start address.
e.g. : In the writing request example (Cf. Table 6) : 0xFF will be write at address 0x10, then 0xAA at address 0x11, 0xBB at address 0x12 and 0xCC at 0x13.

The checksum byte (CSC) is used to detect mistakes during the data transmissions. The master that send the message compute first a checksum and write the result in the last byte of the

Write into EPROM | 0x01 | 0xF4 | 0x00 00 09 | 0xD3 | 0x00 10 | 0x00 00 04 | 0xFF AA BB CC | 0x15 | 0x16
Read from EPROM | 0x01 | 0xF4 | 0x00 00 05 | 0xD4 | 0x00 10 | 0x00 00 04 | - | 0xE2 | 0x16
Read memory ID | 0x01 | 0xF4 | 0x00 00 00 | 0xD5 | - | - | - | 0xCA | 0x16
Send memory ID | 0x01 | 0xF4 | 0x00 00 02 | 0xD5 | - | - | 0x89 0D | 0x60 | 0x16

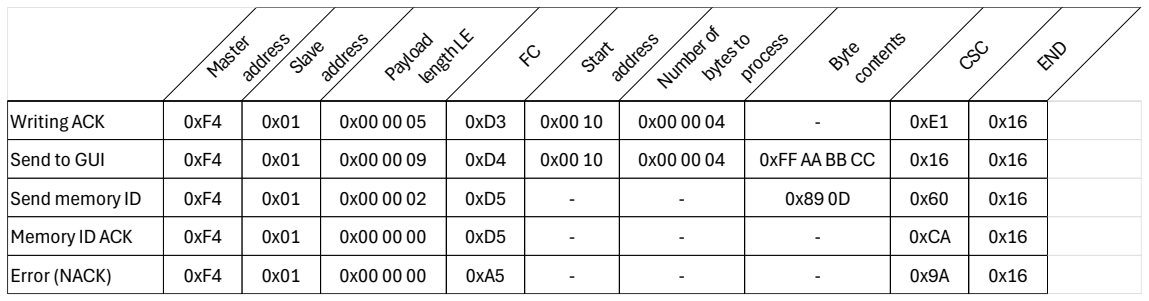
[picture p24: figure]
Master; address Slave; address; Payload; length LE; Start; Number of bytes to; process; Byte; contents; CSC; END

E/E2PROM PROGRAMMER | 24 | L.J

frame. After receiving the frame, the receiver will make the same calculation with the received data and compare it with the CSC computed before the transmission.
The checksum is computing by taking the sum of all the bytes from the master address to the last byte of the byte contents field. The CSC byte is equal to the LSB (least significant byte) of this sum.

e.g. : CSC = (0x01 + 0xF4 + 0xD3 + 0x09 + 0x10 +0x04 +0xFF + 0xAA +0xBB + 0xCC) & 0xFF

CSC = (0x515) & 0xFF = 0x15

Each frame is ending by the END byte ‘0x16’.

## STM32 answer frame

Ack stands from acknowledgement to confirm that the bytes were written while the send to GUI frame is an answer to a previous GUI reading memory request.

Table 7 : Communication protocol – STM32 read/write answer frames

In this example (Cf. Table 7) the payload is equal to 0x02 as the content of the frame is only constituted of the 2 bytes of memory identification (1 byte for the manufacturer ID and 1 byte for the device code).

Writing ACK | 0xF4 | 0x01 | 0x00 00 05 | 0xD3 | 0x00 10 | 0x00 00 04 | - | 0xE1 | 0x16
Send to GUI | 0xF4 | 0x01 | 0x00 00 09 | 0xD4 | 0x00 10 | 0x00 00 04 | 0xFF AA BB CC | 0x16 | 0x16
Send memory ID | 0xF4 | 0x01 | 0x00 00 02 | 0xD5 | - | - | 0x89 0D | 0x60 | 0x16
Memory ID ACK | 0xF4 | 0x01 | 0x00 00 00 | 0xD5 | - | - | - | 0xCA | 0x16
Error (NACK) | 0xF4 | 0x01 | 0x00 00 00 | 0xA5 | - | - | - | 0x9A | 0x16

E/E2PROM PROGRAMMER | 25 | L.J

## XI. Amelioration points

LEDs connected through a 220 Ω resistor directly to a D27C512 output cause the voltage to drop to around 2.5 V because the CMOS EPROM can only source a few milliamps and cannot drive the LED current fully. In contrast, the 28C64 outputs 5 V because it is NMOS/TTL and can source and sink more current, enough to drive LEDs with low-resistance resistors.
This difference is due to the chip technology and output drive strength. The output current can be estimated as I =

Vout−Vled

Rserie

≈

5−2
220

≈ 14mA, which exceeds the safe current for a CMOS EPROM, causing the voltage to sag.
When using a 74HC165 shift register powered at 4.5 V, the VIH = 3.15 V is higher than the 2.5 V EPROM output, resulting in undefined logic levels for the microcontroller.
In a future design, the EPROM outputs should drive the gate of an N-channel MOSFET, with the resistor and LED connected to the drain and the source tied to ground, allowing proper current driving without voltage drop. That would however require more space on the PCB.

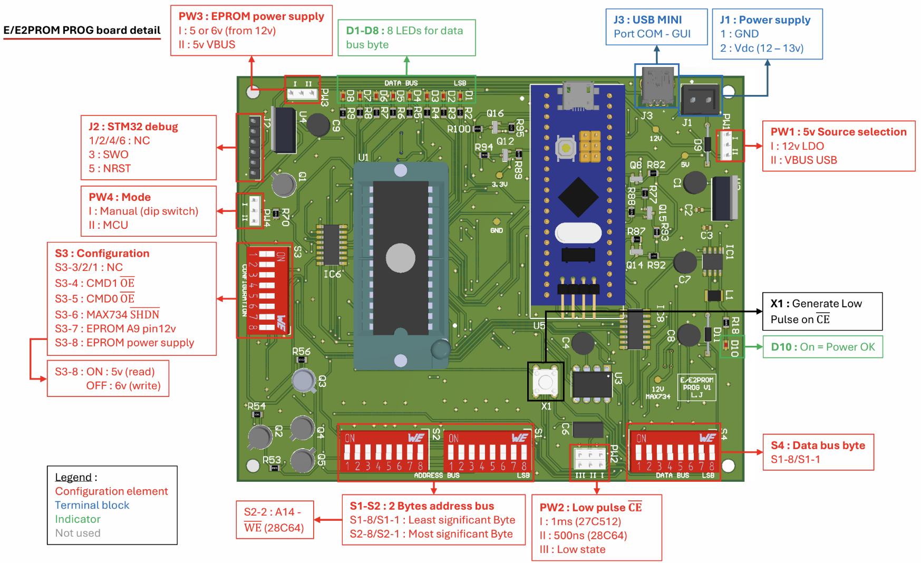
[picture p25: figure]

E/E2PROM PROGRAMMER | 26 | L.J

## XII. Quick starter guide

Figure 20 : Board quick starter guide

E/E2PROM PROGRAMMER | 27 | L.J

## XIII. Annexe

## Annexe 1 : Demonstration of LM317 output voltage equation

IR1 = IR2 =

Vout
R1 + R2

VR2 = R2 × iR2 = Vout

R2
R1 + R2

Vout − VADJ = Vref

IR1 =

Vref
R1

and IR2 = IR1 + IADJ

VR2 = R2(IR1 + IADJ) = R2 (

Vref
R1

+ IADJ)

Thus,

Vout = VR1 + VR2 = Vref (1 +

R2
R1

) + R2 × IADJ

Then, as IADJ ≈ 50μA we can neglect it

Vout = Vref (1 +

R2
R1
) | XIII.1

## Annexe 2 : Demonstration of the capacitor charge equation

ic = C

dVc
dt and E = Vcc = VR + VC

E = RC

dVc
dt + Vc

dVc
dt +

1
RC Vc =

E
RC

Second order linear equation with constant coefficients : dVc
dt +

1
τ

Vc =

E
τ

, τ = RC

- Solution of homogeneous equation (transitional regime) : dVc
dt = −

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
= ∫ −

1
τ

dt + k , k ∈ ℝ

ln(Vc

) = −

t
τ

+ k

E/E2PROM PROGRAMMER | 28 | L.J

Vcℎ = e

−

t
τ

+k = λe⁻

t
τ , λ = e

k

- Particular solution (steady state) : dVc
dt +

1
τ

Vc =

E
τ

, VcPS = E

- General solution :
Vc(t) = Vcℎ

(t) + VcPS(t) = λe⁻

t
τ + E

Initial conditions : Vc

(t = 0) = 0 (capacitor initially discharged) Vc

(t = 0) = λ + E = 0
λ = −E
So,

Vc(t) = E(1 − e
−

t
τ) | XIII.2

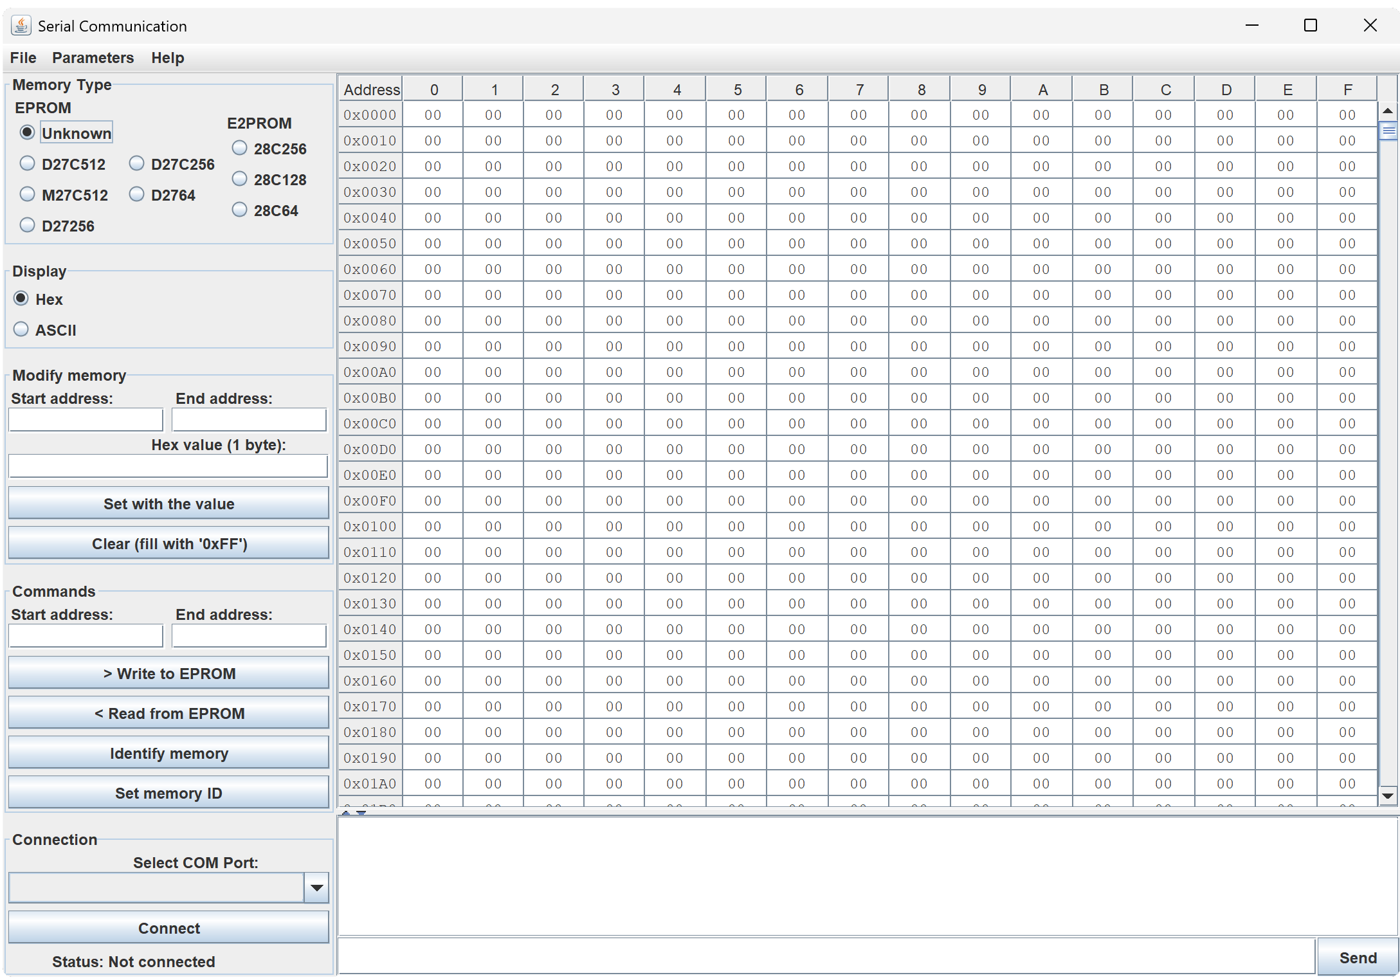
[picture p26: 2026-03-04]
images/EPROM_prog_GUI.png

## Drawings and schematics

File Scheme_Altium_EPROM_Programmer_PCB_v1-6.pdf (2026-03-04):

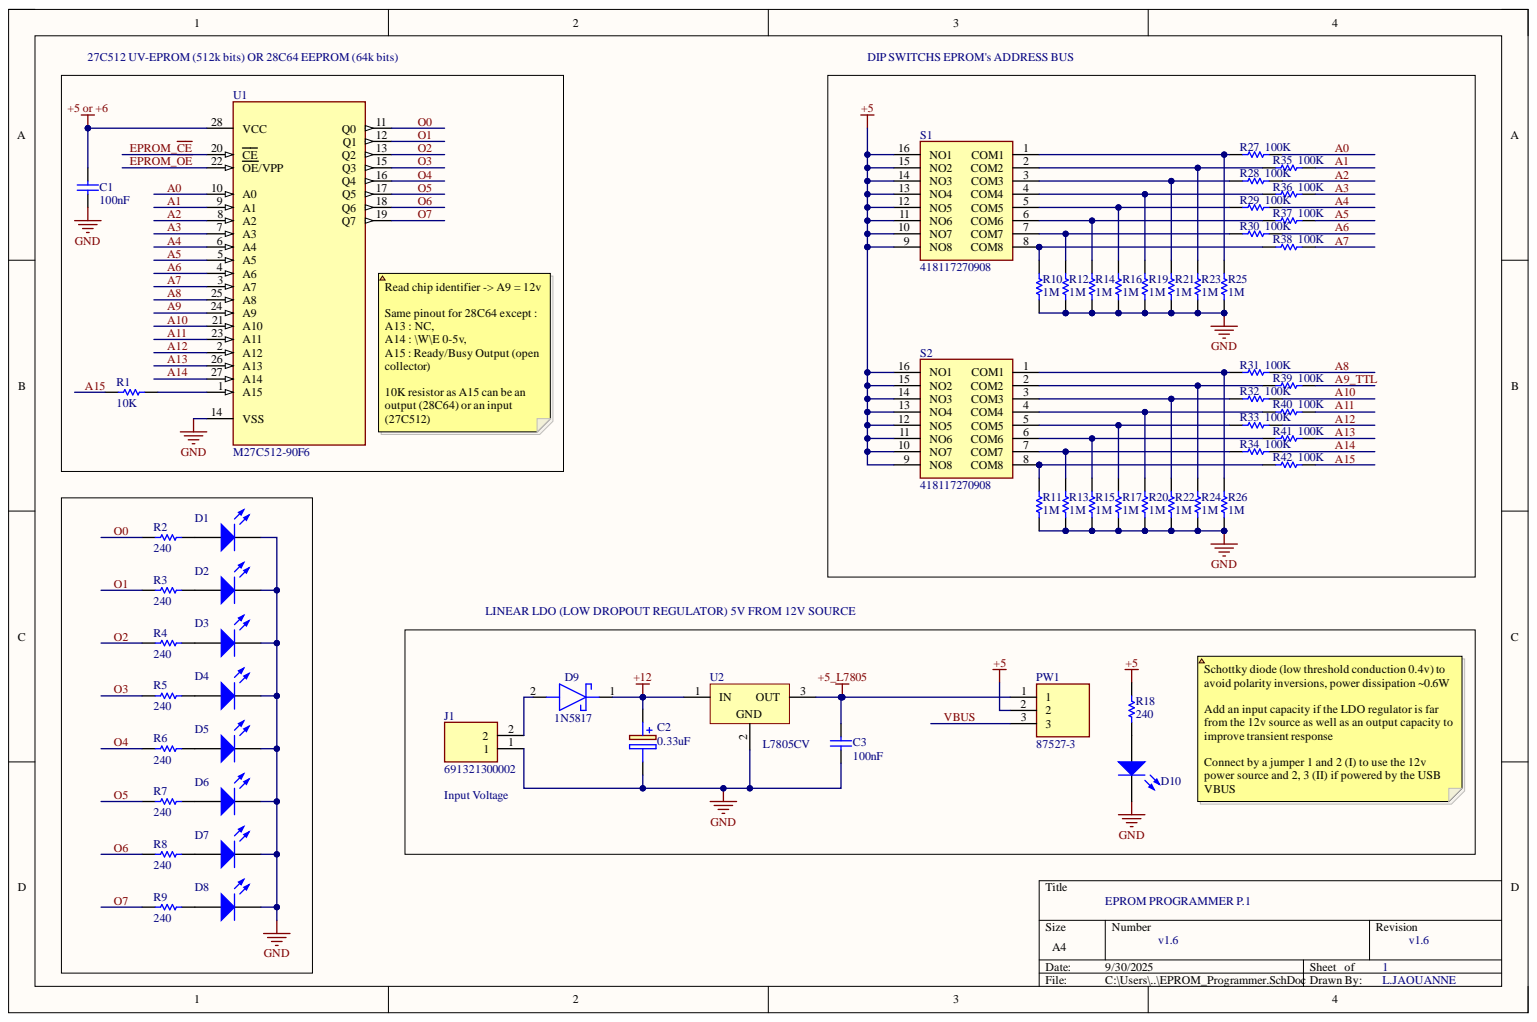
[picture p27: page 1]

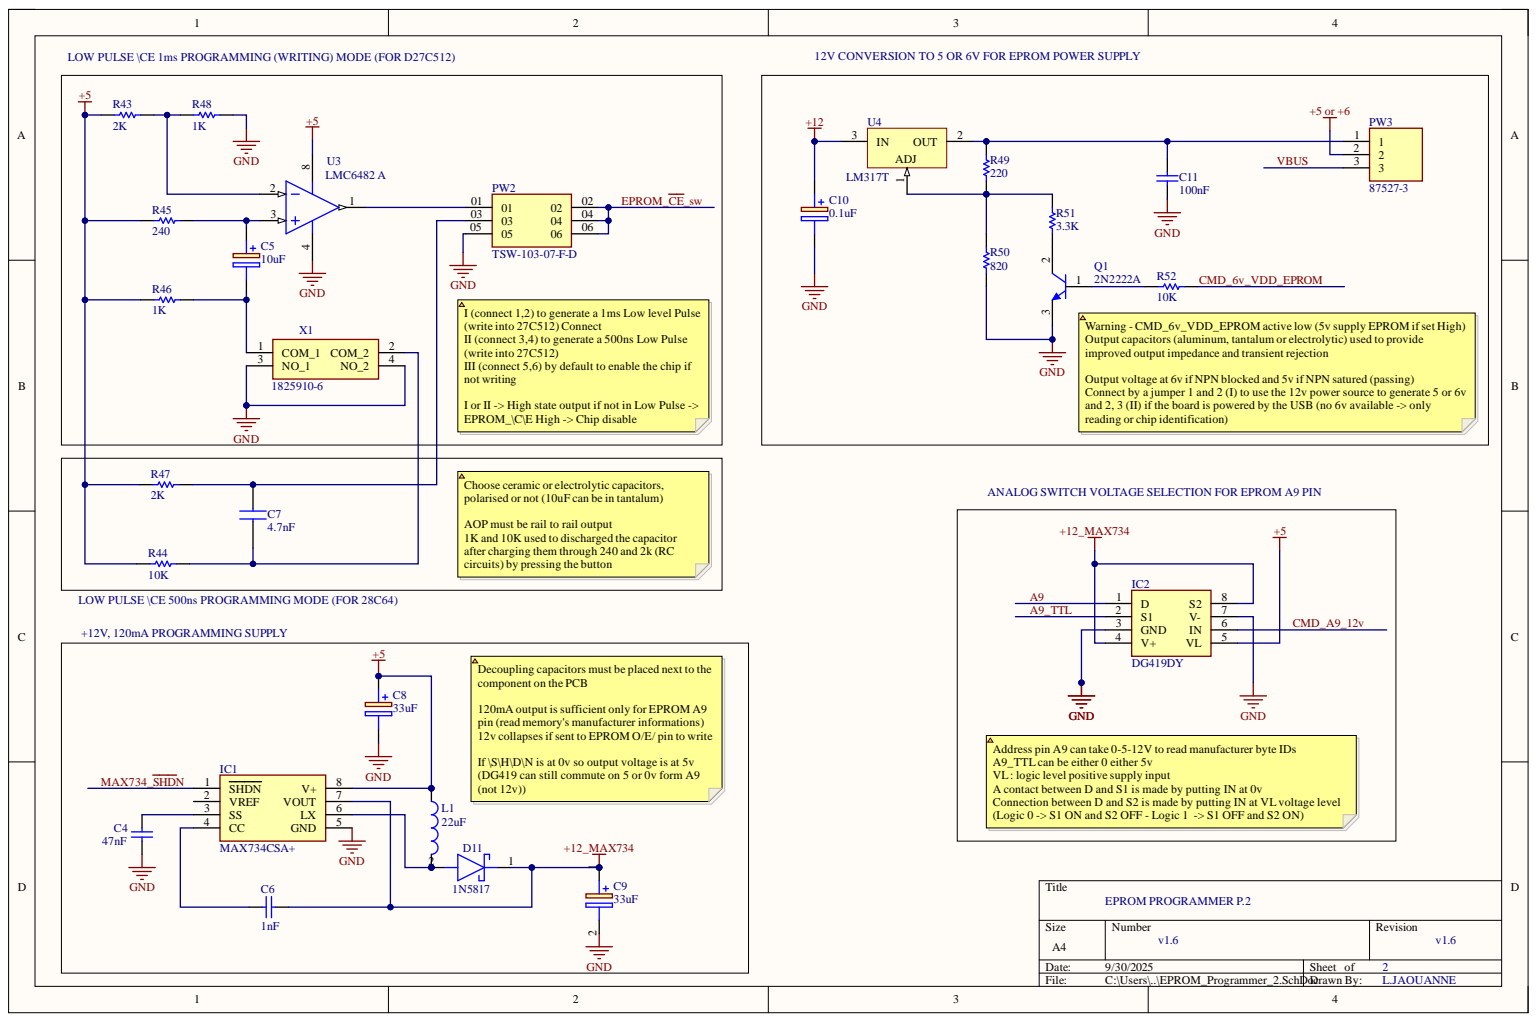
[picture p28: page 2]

LOW PULSE \CE 1ms PROGRAMMING (WRITING) MODE (FOR D27C512)

12V CONVERSION TO 5 OR 6V FOR EPROM POWER SUPPLY

I (connect 1,2) to generate a 1ms Low level Pulse
(write into 27C512) Connect
II (connect 3,4) to generate a 500ns Low Pulse
(write into 27C512)
III (connect 5,6) by default to enable the chip if
not writing

Warning - CMD_6v_VDD_EPROM active low (5v supply EPROM if set High)
Output capacitors (aluminum, tantalum or electrolytic) used to provide
improved output impedance and transient rejection

Output voltage at 6v if NPN blocked and 5v if NPN satured (passing)
Connect by a jumper 1 and 2 (I) to use the 12v power source to generate 5 or 6v
and 2, 3 (II) if the board is powered by the USB (no 6v available -> only
reading or chip identification)

I or II -> High state output if not in Low Pulse ->
EPROM_\C\E High -> Chip disable

Choose ceramic or electrolytic capacitors,
polarised or not (10uF can be in tantalum)

ANALOG SWITCH VOLTAGE SELECTION FOR EPROM A9 PIN

AOP must be rail to rail output
1K and 10K used to discharged the capacitor
after charging them through 240 and 2k (RC
circuits) by pressing the button

LOW PULSE \CE 500ns PROGRAMMING MODE (FOR 28C64)

Decoupling capacitors must be placed next to the
component on the PCB

120mA output is sufficient only for EPROM A9
pin (read memory's manufacturer informations)
12v collapses if sent to EPROM O/E/ pin to write

Address pin A9 can take 0-5-12V to read manufacturer byte IDs
A9_TTL can be either 0 either 5v
VL: logic level positive supply input
A contact between D and S1 is made by putting IN at 0v
Connection between D and S2 is made by putting IN at VL voltage level
(Logic 0 -> S1 ON and S2 OFF - Logic 1 -> S1 OFF and S2 ON)

If \S\H\D\N is at 0v so output voltage is at 5v
(DG419 can still commute on 5 or 0v form A9
(not 12v))

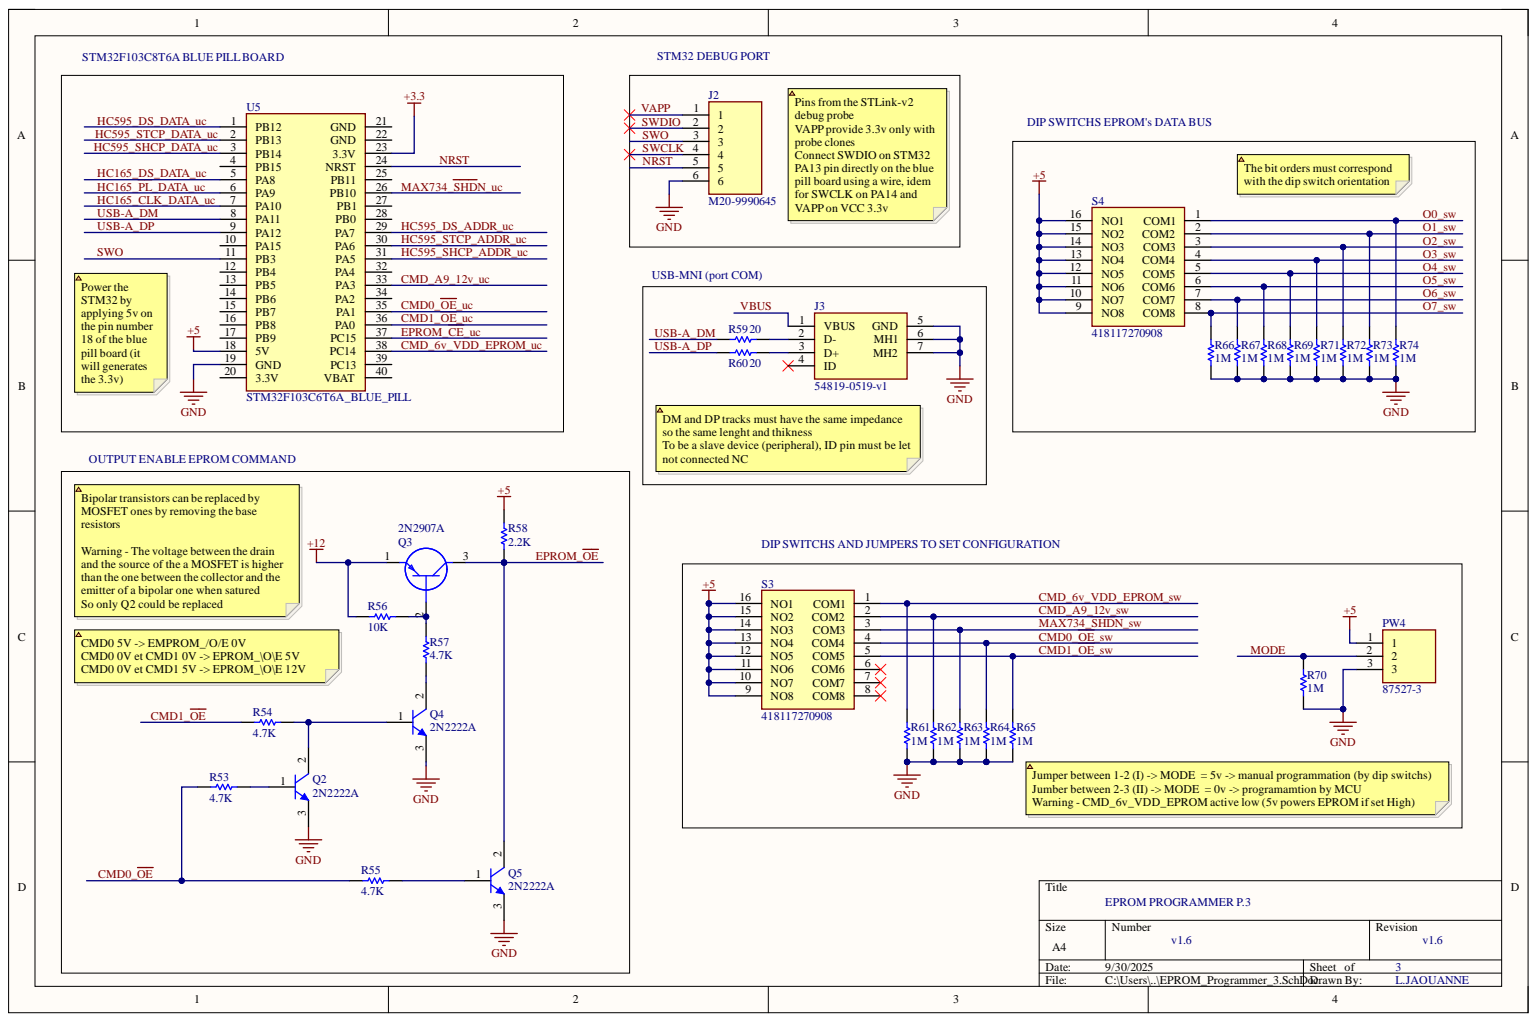
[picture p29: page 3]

Pins from the STLink-v2
debug probe
VAPP provide 3.3v only with
probe clones
Connect SWDIO on STM32
PA13 pin directly on the blue
pill board using a wire, idem
for SWCLK on PA14 and
VAPP on VCC 3.3v

DIP SWITCHS EPROM's DATA BUS

The bit orders must correspond
with the dip switch orientation

USB-MNI (port COM)

DM and DP tracks must have the same impedance
so the same lenght and thikness
To be a slave device (peripheral), ID pin must be let
not connected NC

OUTPUT ENABLE EPROM COMMAND

Bipolar transistors can be replaced by
MOSFET ones by removing the base
resistors

DIP SWITCHS AND JUMPERS TO SET CONFIGURATION

Warning - The voltage between the drain
and the source of the a MOSFET is higher
than the one between the collector and the
emitter of a bipolar one when satured
So only Q2 could be replaced

Jumper between 1-2 (I) -> MODE = 5v -> manual programmation (by dip switchs)
Jumber between 2-3 (II) -> MODE = 0v -> programamtion by MCU
Warning - CMD_6v_VDD_EPROM active low (5v powers EPROM if set High)

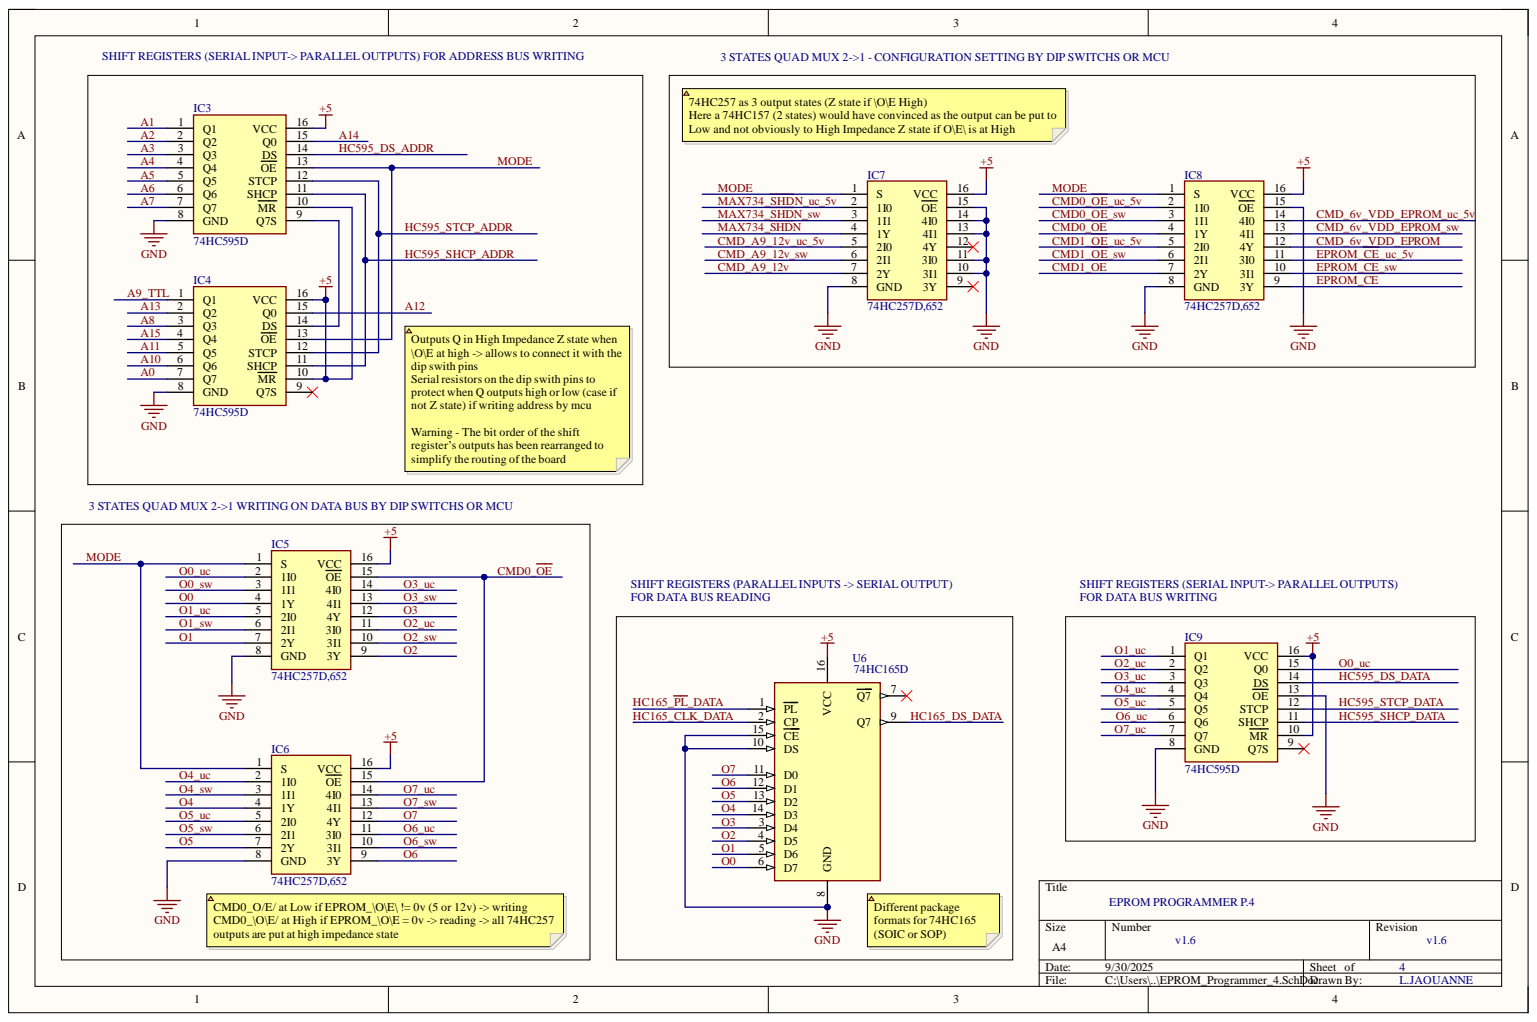
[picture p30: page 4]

SHIFT REGISTERS (SERIAL INPUT-> PARALLEL OUTPUTS) FOR ADDRESS BUS WRITING

3 STATES QUAD MUX 2->1 - CONFIGURATION SETTING BY DIP SWITCHS OR MCU

74HC257 as 3 output states (Z state if \O\E High)
Here a 74HC157 (2 states) would have convinced as the output can be put to
Low and not obviously to High Impedance Z state if O\E\ is at High

Outputs Q in High Impedance Z state when
\O\E at high -> allows to connect it with the
dip swith pins
Serial resistors on the dip swith pins to
protect when Q outputs high or low (case if
not Z state) if writing address by mcu

Warning - The bit order of the shift
register’s outputs has been rearranged to
simplify the routing of the board

3 STATES QUAD MUX 2->1 WRITING ON DATA BUS BY DIP SWITCHS OR MCU

SHIFT REGISTERS (PARALLEL INPUTS -> SERIAL OUTPUT)

SHIFT REGISTERS (SERIAL INPUT-> PARALLEL OUTPUTS)

CMD0_O/E/ at Low if EPROM_\O\E\ != 0v (5 or 12v) -> writing
CMD0_\O\E/ at High if EPROM_\O\E = 0v -> reading -> all 74HC257
outputs are put at high impedance state

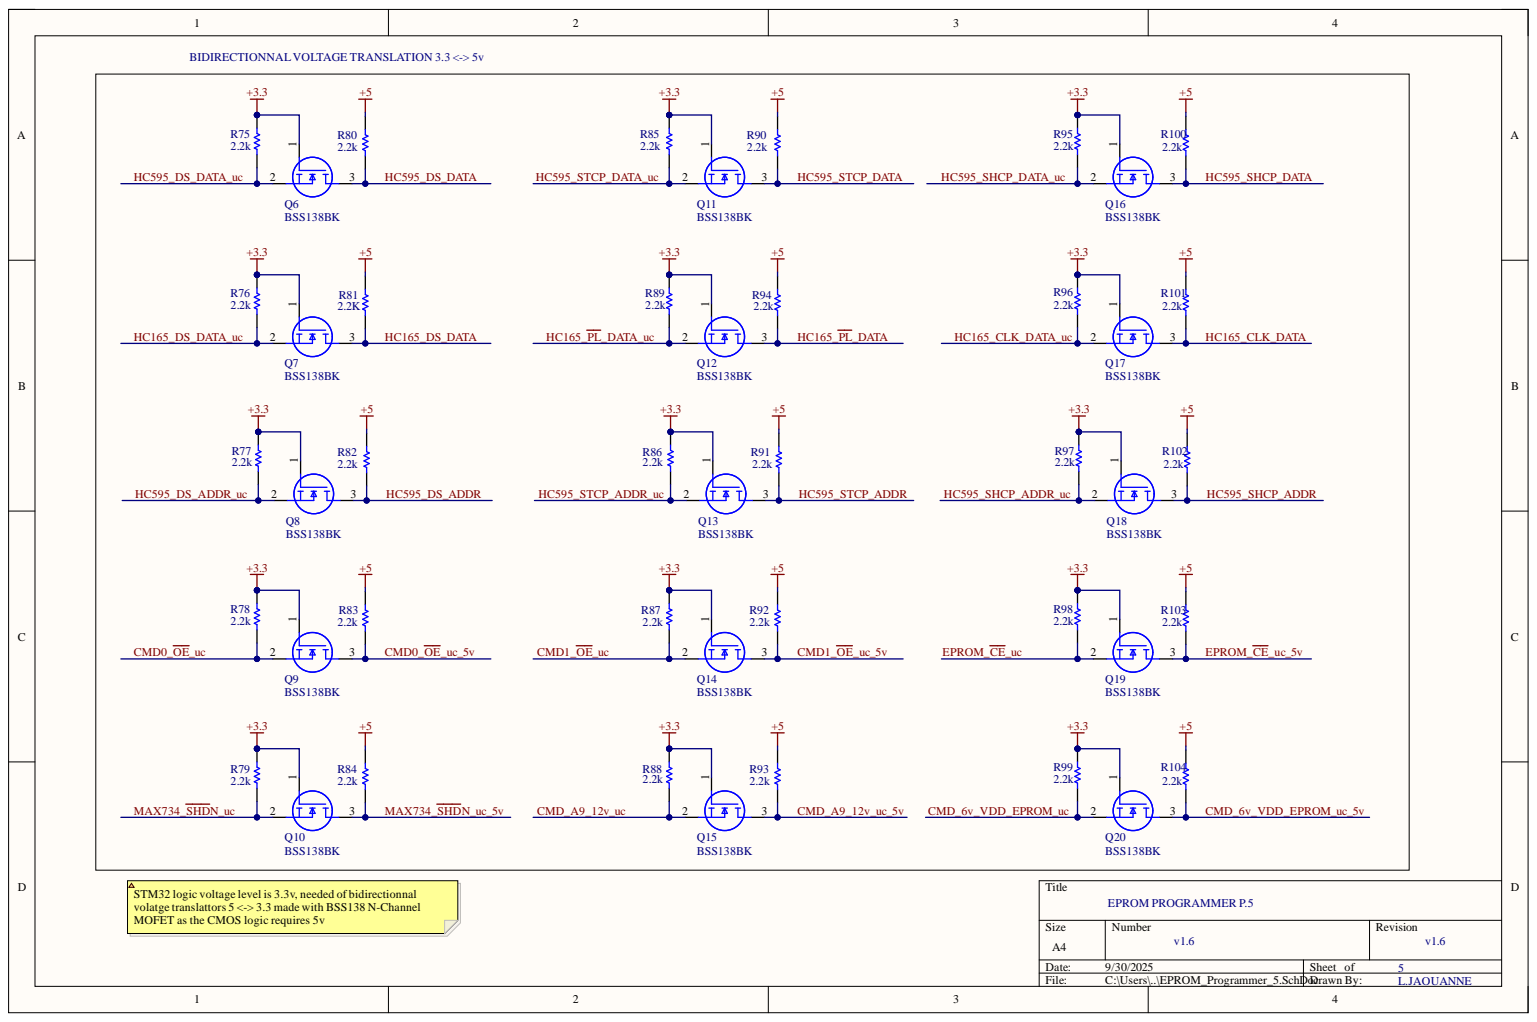
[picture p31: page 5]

STM32 logic voltage level is 3.3v, needed of bidirectionnal
volatge translattors 5 <-> 3.3 made with BSS138 N-Channel
MOFET as the CMOS logic requires 5v
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

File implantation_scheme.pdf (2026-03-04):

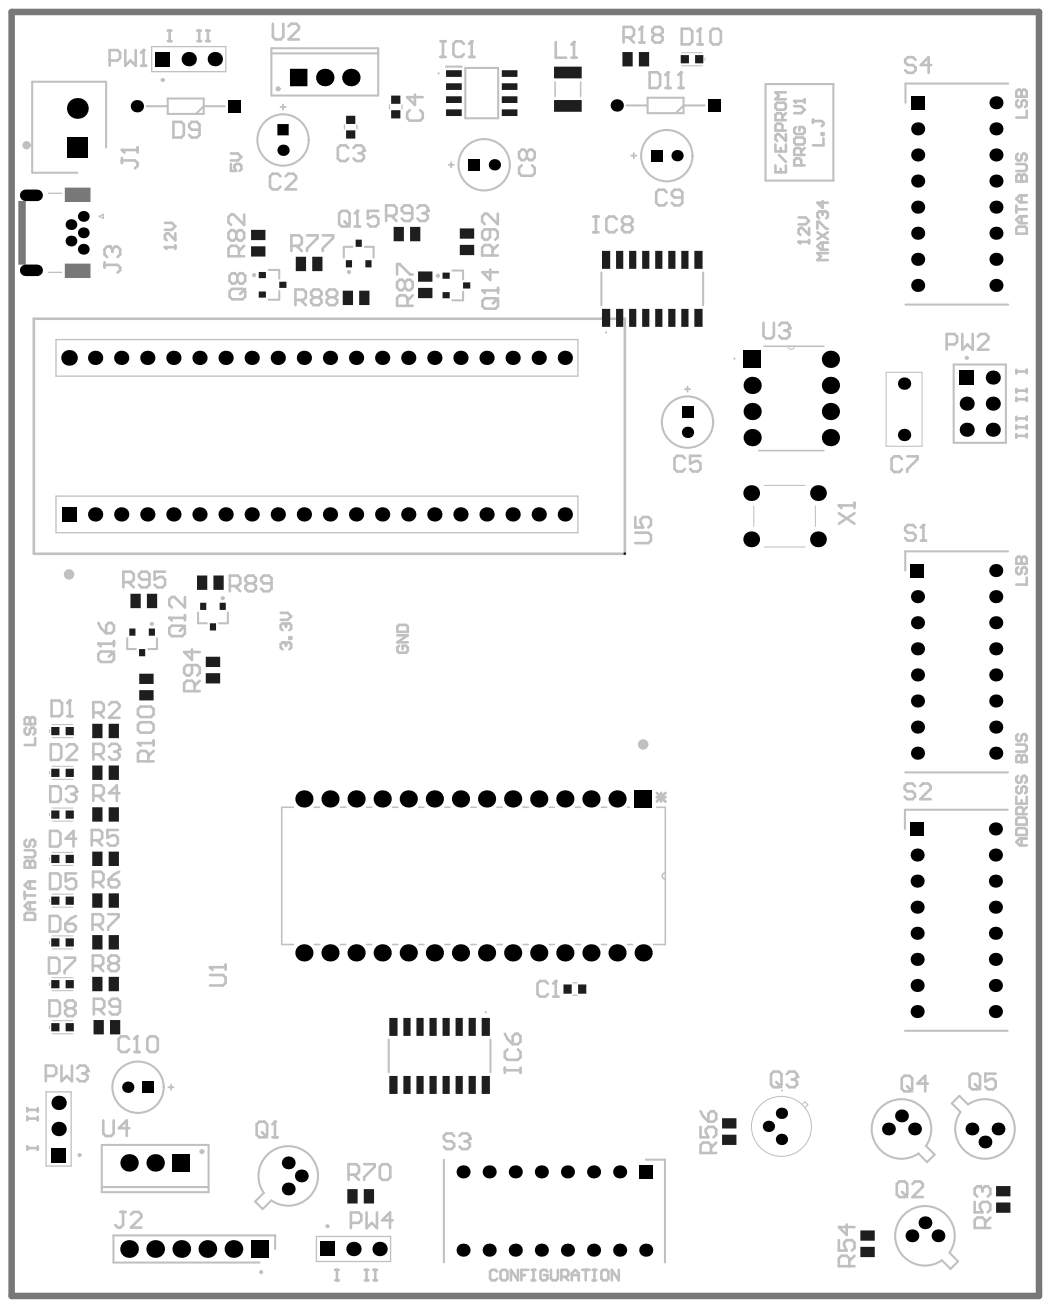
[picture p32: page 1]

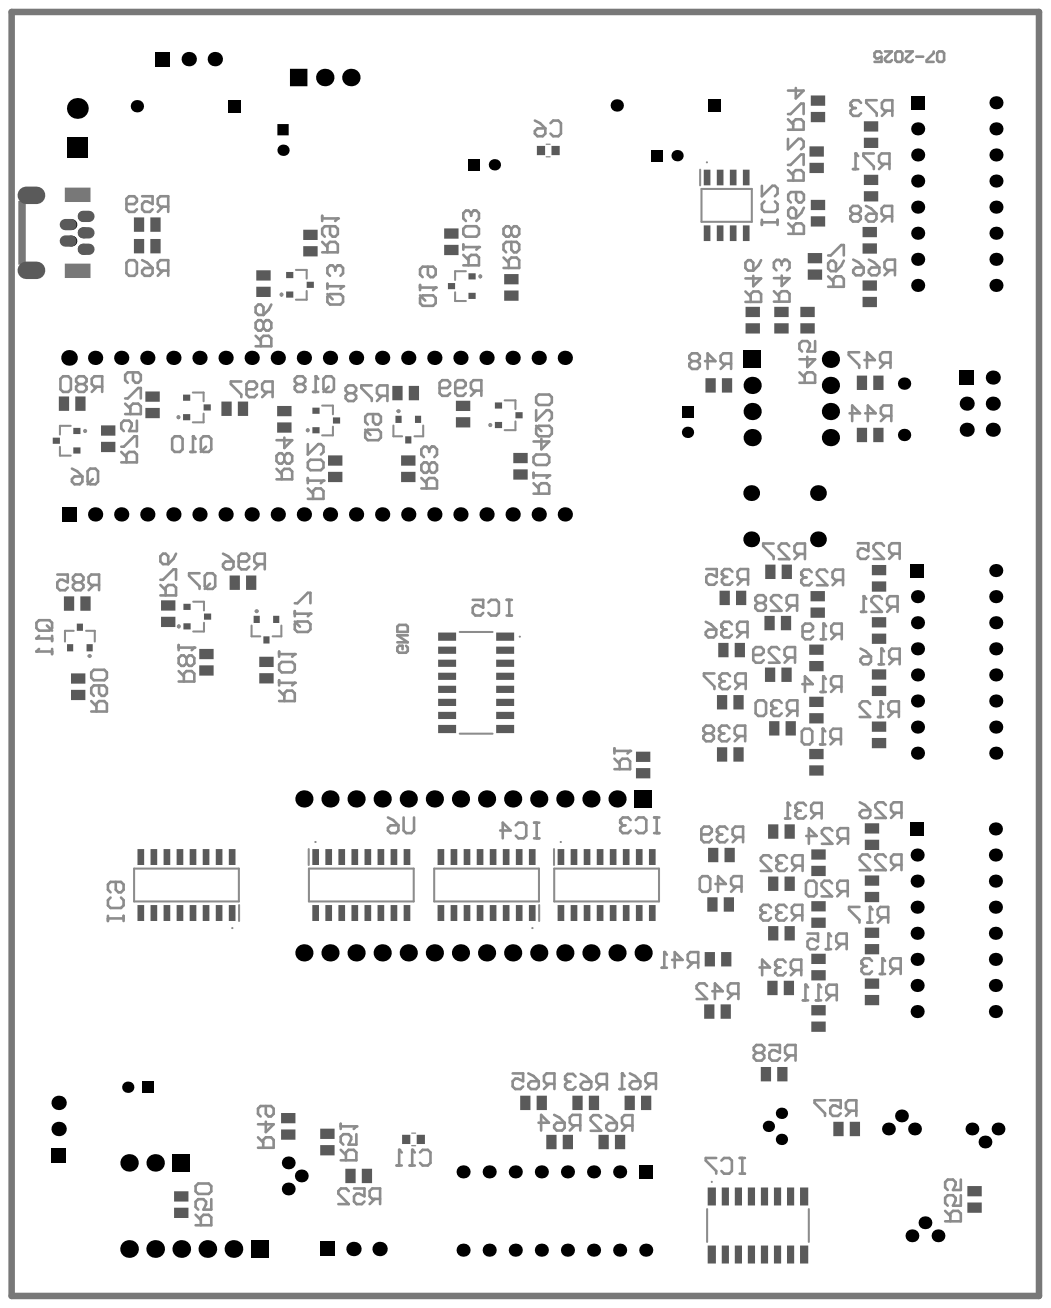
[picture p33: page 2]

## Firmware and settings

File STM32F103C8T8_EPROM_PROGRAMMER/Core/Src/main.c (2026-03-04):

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
/* Includes ------------------------------------------------------------------*/
#include "main.h"
#include "usb_device.h"

/* USER CODE BEGIN Includes */
#include "usbd_cdc_if.h"
#include "com_usb.h"
#include "shift_registers.h"
#include "eprom_cmds.h"

//#include "stm32f1xx_hal.h"
//#include "stm32f1xx_hal_pcd.h"  // For USB

/* USER CODE END Includes */

TIM_HandleTypeDef htim2;
TIM_HandleTypeDef htim3;

void SystemClock_Config(void);
static void MX_GPIO_Init(void);
static void MX_TIM2_Init(void);
static void MX_TIM3_Init(void);
/* USER CODE BEGIN 0 */
//global variables
//uint8_t TxBuffer[] = "Hello From STM32 USB CDC Device To Virtual COM Port\r\n";
//char *data = "Hello from STM\n";
uint8_t buffer[SIZE_OF_BUFFER];
uint16_t len = 0;
uint8_t rx_usb_buf[SIZE_OF_BUFFER];

Flag flag_rx_usb = Idle;

//uint8_t memory[2048];

/* USER CODE END 0 */

/**
  * @brief  The application entry point.
  * @retval int
  */
int main(void)
{
  /* MCU Configuration--------------------------------------------------------*/

  /* Reset of all peripherals, Initializes the Flash interface and the Systick. */
  HAL_Init();

  /* Configure the system clock */
  SystemClock_Config();

  /* Initialize all configured peripherals */
  MX_GPIO_Init();
  MX_USB_DEVICE_Init();
  MX_TIM2_Init();
  MX_TIM3_Init();
  /* USER CODE BEGIN 2 */

  //// Not needed in SLEEP mode
  //This sets up EXTI18 to listen for USB resume events from suspend mode
//  __HAL_USB_WAKEUP_EXTI_CLEAR_FLAG();   // Clear any pending wake-ups
//  __HAL_USB_WAKEUP_EXTI_ENABLE_IT();    // Enable EXTI line 18 for USB resume/wake-up

  if(HAL_TIM_Base_Start_IT(&htim2)!=HAL_OK)
	  Error_Handler();

  HAL_GPIO_WritePin(LD1_GPIO_Port, LD1_Pin, RESET);

  //INIT
  set_EPROM_address(0x4000);//0b1000000 00000000;//TODO : ONLY IF 28C64 BIT 14 HIGH TO BE IN READING MODE
  //set_EPROM_address(0x0000);
  EPROM_reading_config();

//  printf("List Enabled IRQ:\n");
//  for (IRQn_Type irq = 0; irq < USBWakeUp_IRQn; irq++) {
//      if (NVIC_GetEnableIRQ(irq)) {
//          printf("Enabled IRQ: %d\n", irq);
//      }
//  }

  //TODO ADDED for sleep mode
  HAL_PWR_DisableSleepOnExit();//keeps the MCU in main loop after waking from interrupt
  HAL_NVIC_SetPriority(USB_LP_CAN1_RX0_IRQn, 0, 0);
  HAL_NVIC_EnableIRQ(USB_LP_CAN1_RX0_IRQn);  // THIS is the one that wakes on USB traffic

  //tied to EXTI line 18, which is dedicated to USB wake-up from STOP or STANDBY mode not for sleep mode
//  HAL_NVIC_SetPriority(USBWakeUp_IRQn, 0, 0);//assigning highest priority
//  HAL_NVIC_EnableIRQ(USBWakeUp_IRQn);//enabling the USB wake-up interrupt
  /* Manually ensure that USBWakeUp_IRQHandler is declared in the startup file (startup_stm32f103xx.s)
   * so the vector table correctly points to it
   * The USBWakeUp_IRQn corresponds to EXTI line 18, which is triggered by USB resume events
   */


  //the GUI receiver is waiting for a proper
//  uint8_t size_data = strlen(data);
//  CDC_Transmit_FS((uint8_t*)data, size_data);
//  printf("Sent : %s\n",data);

  //imitating a true EPROM content
//  memset(memory, '\0', sizeof(memory));
//  for(int i=0; i<sizeof(memory); i++){
//	  if(i<256)
//		  memory[i]=i;
//	  else
//		  memory[i]=0x3B;
//  }

  printf("\rbegin\n");

  /* USER CODE END 2 */

  /* Infinite loop */
  /* USER CODE BEGIN WHILE */
  while (1)
  {

	  if(flag_rx_usb == Event){
		  plugged_eprom.familly = E2PROM;
		  plugged_eprom.nbr_of_bytes = 8192;//2^13 addresses
		  plugged_eprom.eprom_id = AT28C64;

		  printf("RX - HEX : ");
		  printHex(buffer, len);
//		  printf("received : %s\n",buffer);
		  memcpy(rx_usb_buf, buffer, sizeof(rx_usb_buf));

		  uint16_t start_addr = 0;
		  uint32_t nbr_bytes = 0;

		  if(rx_usb_buf[FC_INDEX]==FC_READ || rx_usb_buf[FC_INDEX]==FC_WRITE){
			  start_addr = (rx_usb_buf[START_ADDR_INEX]<<8) + rx_usb_buf[START_ADDR_INEX+1];//over 2 bytes
			  nbr_bytes = (rx_usb_buf[NBR_BYTES_INDEX]<<16) + (rx_usb_buf[NBR_BYTES_INDEX+1]<<8) + rx_usb_buf[NBR_BYTES_INDEX+2];
		  }

		  if(rx_usb_buf[FC_INDEX]==FC_READ){
			  if(!verify_check_sum(rx_usb_buf, nbr_bytes)){
				  send_acknoledgment_to_GUI(FC_ERROR, start_addr, nbr_bytes);//NACK
			  }
			  else{
				  printf("EPROM->GUI : GUI EPROM memory reading request, start : %04" PRIX16 ", bytes : %06" PRIX32 "\n",start_addr, nbr_bytes);
				  read_and_send_memory_bytes_through_usb(start_addr, nbr_bytes);
			  }
		  }
		  else if(rx_usb_buf[FC_INDEX]==FC_WRITE){
			  if(!verify_check_sum(rx_usb_buf, nbr_bytes)){
				  send_acknoledgment_to_GUI(FC_ERROR, start_addr, nbr_bytes);
			  }
			  else{
				  printf("GUI->EPROM : GUI EPROM memory write request, start : %04" PRIX16 ", bytes : %06" PRIX32 "\n",start_addr, nbr_bytes);
//				  for(int i=0; i<nbr_bytes || i<(sizeof(rx_usb_buf)-CONTENT_INDEX) || i<(sizeof(memory)-start_addr); i++){
//					  memory[start_addr+i] = rx_usb_buf[CONTENT_INDEX+i];
//				  }
				  //identify_chip();
				  //plugged_eprom.eprom_id == D27256;
				  if(plugged_eprom.eprom_id == Unknown){
					  printf("Chip not identified\n");
					  send_acknoledgment_to_GUI(FC_ERROR, start_addr, nbr_bytes);//NACK
				  }
				  //if(nbr_bytes<(sizeof(rx_usb_buf)-CONTENT_INDEX-2) && nbr_bytes<(sizeof(memory)-start_addr)){
				  if(nbr_bytes<(sizeof(rx_usb_buf)-CONTENT_INDEX-2) && nbr_bytes<((plugged_eprom.nbr_of_bytes)-start_addr)){
					  for(int i=0; i<nbr_bytes; i++)
						  writeEPROM(start_addr+i, rx_usb_buf[CONTENT_INDEX+i]);

					  //memcpy(&memory[start_addr], &rx_usb_buf[CONTENT_INDEX], nbr_bytes);
				  	  send_acknoledgment_to_GUI(FC_WRITE, start_addr, nbr_bytes);
				  }
				  else{
					  printf("nbr_bytes out of range\n");
					  send_acknoledgment_to_GUI(FC_ERROR, start_addr, nbr_bytes);//NACK
				  }
			  }
		  }
		  else if(rx_usb_buf[FC_INDEX]==FC_ID_MEM){
			  if(!verify_check_sum(rx_usb_buf, nbr_bytes)){
				  send_acknoledgment_to_GUI(FC_ERROR, 0, 0);//NACK
			  }
			  else{
				  printf("GUI->EPROM : GUI EPROM memory identification request");

				  uint8_t manufacturerID = 0, deviceCode = 0;

				  uint16_t ID_chip_bytes = read_ID_chip_EPROM();
				  manufacturerID = (ID_chip_bytes>>8)&0xFF;
				  deviceCode = ID_chip_bytes&0xFF;
//				  manufacturerID = 0x89;
//				  deviceCode = 0x08;

				  send_memory_id_to_GUI(FC_ID_MEM, manufacturerID, deviceCode);
			  }
		  }
		  else{
			  send_acknoledgment_to_GUI(FC_ERROR, 0, 0);//NACK
		  }

		  flag_rx_usb = Idle;
	  }

//	  enter_and_get_out_sleep_mode();

    /* USER CODE END WHILE */

    /* USER CODE BEGIN 3 */
  }
  /* USER CODE END 3 */
}

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
/* USER CODE BEGIN 4 */
//printf function avec pin debug SWO
int __io_putchar(int ch) {
    ITM_SendChar(ch);
    return ch;
}
void HAL_TIM_PeriodElapsedCallback(TIM_HandleTypeDef *htim){
	static int count = 0;

	if(htim->Instance == htim2.Instance){//1s tick
		count++;
		if(count%1==0)
			HAL_GPIO_TogglePin(LD1_GPIO_Port, LD1_Pin);
//		if(count%5==0){//every 5sec
//			uint8_t size_data = strlen(data);
//			CDC_Transmit_FS((uint8_t*)data, size_data);
//			printf("Sent : %s",data);
//		}
	}
//	else if(htim->Instance == htim3.Instance){//1us tick (1MHz)
//		tick_timer3_1us = 1;//used to toggle the state of \CE to write the 28C64
//	}
}

void enter_and_get_out_sleep_mode(void){
	//printf("Entering sleep mode...\n");
	/* Enter sleep after handling event
	 * wake up the MCU only when data is received on the USB
	 * in SLEEP mode only the CPU is disabled, all the peripherals are working*/

	__HAL_TIM_DISABLE_IT(&htim2, TIM_IT_UPDATE);//Disable TIM2 interrupt so it does not wake CPU

	// Not needed in SLEEP mode
	//	  __HAL_USB_WAKEUP_EXTI_CLEAR_FLAG();   // clear the EXTI flag before sleeping, to avoid false wake-ups
	//	  __HAL_USB_WAKEUP_EXTI_ENABLE_IT();    // Enable EXTI line 18 for USB resume/wake-up

	HAL_SuspendTick();//Stop the SysTick timer to avoid waking the CPU every 1ms
	//Enter sleep mode — only USB IRQ will wake it -> IRQ generates USB_LP_CAN1_RX0_IRQHandler in stm32f1xx_it.c
	HAL_PWR_EnterSLEEPMode(PWR_LOWPOWERREGULATOR_ON, PWR_SLEEPENTRY_WFI);//WFI (Wait For Interrupt)
	HAL_ResumeTick();//CPU Has Exited From Sleep Mode, Resume The SysTick

	__HAL_TIM_ENABLE_IT(&htim2, TIM_IT_UPDATE);//Re-enable TIM2 interrupt for LED blinking

	//by using USB CDC, SOF (Start Of Frame) interrupts are likely active. These happen every 1ms and wake the MCU
	//printf("Woke up!\n");
}

// Assume APB1 timer clock = 72 MHz
// Configure TIM3 as 1 MHz tick (1 µs per tick)
void low_pulse_CE_1us(void) {
    __HAL_TIM_SET_COUNTER(&htim3, 0);
    HAL_GPIO_WritePin(EPROM__CE_GPIO_Port, EPROM__CE_Pin, GPIO_PIN_RESET); // Low, enable (chip select active low)

    HAL_TIM_Base_Start(&htim3);//do not start IT
    while(__HAL_TIM_GET_COUNTER(&htim3) < 1) {
        __NOP();  // Wait exactly 1 µs
    }
    HAL_TIM_Base_Stop(&htim3);

    HAL_GPIO_WritePin(EPROM__CE_GPIO_Port, EPROM__CE_Pin, GPIO_PIN_SET);   // High
}


/* USER CODE END 4 */
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


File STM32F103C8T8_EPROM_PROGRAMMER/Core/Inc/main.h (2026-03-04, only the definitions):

#define SIZE_OF_BUFFER 2048//64
#define LD1_Pin GPIO_PIN_13
#define LD1_GPIO_Port GPIOC
#define HC595_DS_ADDR_Pin GPIO_PIN_7//SHIFT_DATA
#define HC595_DS_ADDR_Port GPIOA
#define HC595_STCP_ADDR_Pin GPIO_PIN_6//SHIFT_LATCH : latch clock - send bits to Q0 - Q7
#define HC595_STCP_ADDR_Port GPIOA
#define HC595_SHCP_ADDR_Pin GPIO_PIN_5//SHIFT_CLOCK : shift register clock - every rising edge shift of 1 bit
#define HC595_SHCP_ADDR_Port GPIOA
#define HC595_DS_DATA_Pin GPIO_PIN_12//SHIFT_DATA
#define HC595_DS_DATA_Port GPIOB
#define HC595_STCP_DATA_Pin GPIO_PIN_13//SHIFT_LATCH
#define HC595_STCP_DATA_Port GPIOB
#define HC595_SHCP_DATA_Pin GPIO_PIN_14//SHIFT_CLOCK
#define HC595_SHCP_DATA_Port GPIOB
#define HC165__PL_DATA_Pin GPIO_PIN_9//NOT PL
#define HC165__PL_DATA_GPIO_Port GPIOA
#define HC165_DS_DATA_Pin GPIO_PIN_8//pin Q7
#define HC165_DS_DATA_GPIO_Port GPIOA
#define HC165_CLK_DATA_Pin GPIO_PIN_10
#define HC165_CLK_DATA_GPIO_Port GPIOA
#define MAX734__SHDN_Pin GPIO_PIN_10//NOT shutdown - 12v generation from 5v input source
#define MAX734__SHDN_GPIO_Port GPIOB
#define CMD_A9_12V_Pin GPIO_PIN_3//pin number 9 of address bus to 12v to read the memory identification bytes
#define CMD_A9_12V_GPIO_Port GPIOA
#define CMD0__OE_Pin GPIO_PIN_1//EPROM__OE Low if CMD__OE High
#define CMD0__OE_GPIO_Port GPIOA
#define CMD1__OE_Pin GPIO_PIN_0//if CMD1__OE High & CMD0__OE Low EPROM__OE to 12v else if CMD1__OE Low & CMD0__OE Low EPROM__OE to 5v
#define CMD1__OE_GPIO_Port GPIOA
#define EPROM__CE_Pin GPIO_PIN_15//NOT chip select if high (active low)
#define EPROM__CE_GPIO_Port GPIOC
#define CMD_6V_VDD_EPROM_Pin GPIO_PIN_14//5v for reading if high either 6v to write if low
#define CMD_6V_VDD_EPROM_GPIO_Port GPIOC
#define MEMORY_SIZE_kb 512//kbits (512kb bits = 64kB bytes)
#define NUMBER_BYTES_PER_ROW 16//from 0x00 to 0x0F
#define MEMORY_ROW MEMORY_SIZE_kb/8*1024/NUMBER_BYTES_PER_LINE //should equal 4096 row (from 0x0000 to 0xFFF0)

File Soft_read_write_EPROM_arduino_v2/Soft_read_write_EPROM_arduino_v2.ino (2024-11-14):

#define Pin_DS 2 //SHIFT_DATA
#define Pin_STCP 4 //SHIFT_LATCH
#define Pin_SHCP 3 //SHIFT_CLOCK
#define numberOf74hc595 2//nbr de registres a decalage utilises
#define numOfRegisterPins numberOf74hc595*8//number of total register pins

#define CMD_OE_BAR_0V A4 //output enable active low from UV-EPROM INTEL 27512
#define CMD_OE_BAR_12V_5V A3 //12v si high et CMD_OE_BAR_OV low, 0 ou 5v sinon
#define CE_bar A5 //Chip select active low of EPROM, A0 corresponds to digital pin 14
#define CMD_ALIM_EPROM_5V_6V A2//5v for reading if high ether 6v to write if low
#define EPROM_D0 6
#define EPROM_D7 13

#define MEMORY_SIZE 512

bool CE_enable = false, CE_disable = true;

//global variable
bool registers[numOfRegisterPins];//create an array with boolean, size of pin of 74HC595

void clearRegisters();
void writeRegisters();
void setRegisterPin(int index, int value);
void setAddress(int address);
byte readEPROM(int address);
void writeEPROM(int address, byte data);
void printContents();

void setup() {
  Serial.begin(9600);
  
  pinMode(Pin_DS, OUTPUT);
  pinMode(Pin_STCP, OUTPUT);
  pinMode(Pin_SHCP, OUTPUT);
  
  clearRegisters();//reset the array for all register pins
  writeRegisters();// write value on shift register
  
  for(int pin = EPROM_D7; pin >= EPROM_D0; pin -= 1){
    pinMode(pin, INPUT);
  }
  /*
  int address_to_write[] = {0x00F7, 0x00F8, 0x00F9};
  byte data_to_write[] = {0xAA, 0xAB, 0xAC};
  writeEPROM(0x00F3, 0x3A);
  
  for (int i=0; i<3; i++){
    writeEPROM(address_to_write[i], data_to_write[i]);
  }
  */
  printContents();
}

void loop(){

}  

//set all register pins to LOW
void clearRegisters(){
  for(int i = numOfRegisterPins - 1; i >=  0; i--){
     registers[i] = LOW;
  }
} 

// set value recorded in array "registers" and display on the end
void writeRegisters(){
  int val = 0;
  digitalWrite(Pin_STCP, LOW); // Until LOW modification wont be apply
  for(int i = numOfRegisterPins - 1; i >=  0; i--){ // loop for aplly all value for each pin 74hc595
    digitalWrite(Pin_SHCP, LOW);//need to be low for change column soon
    val = registers[i];// catch value insinde array registers
    digitalWrite(Pin_DS, val);//apply the value to a pin of 74hc595
    digitalWrite(Pin_SHCP, HIGH);// rising edge for clock and then next column
  }
  digitalWrite(Pin_STCP, HIGH);// apply value to all pin of 74hc595

}

//set an individual pin HIGH or LOW
void setRegisterPin(int index, int value){
  registers[index] = value;
}

/*
 * Output the address bits and outputEnable signal using shift registers.
 */
void setAddress(int address){
  for(int i=0; i<numOfRegisterPins; i++){
    setRegisterPin(i, address & (0b1<<i));
  }
  writeRegisters();// write value on shift register
}

/*
 * Read a byte from the EEPROM at the specified address.
 */
byte readEPROM(int address) {
  digitalWrite(CMD_ALIM_EPROM_5V_6V, HIGH);//alim 5v
  setAddress(address);//set the 16 bits of address bus from A0 to A16 of the EPROM
  digitalWrite(CMD_OE_BAR_0V, HIGH);//put to low state the pin to enable Outputs
  digitalWrite(CE_bar, CE_enable);
  for (int pin = EPROM_D0; pin <= EPROM_D7; pin += 1) {
    pinMode(pin, INPUT);
  }
  byte data = 0;
  for(int pin = EPROM_D7; pin >= EPROM_D0; pin -= 1){
    data = (data << 1) + digitalRead(pin);
  }
  return data;//return the 8 bits of data bus read
}

/*
 * Write a byte to the EEPROM at the specified address.
 */
void writeEPROM(int address, byte data) {
  digitalWrite(CMD_ALIM_EPROM_5V_6V, LOW);//alim 6v, commande NPN
  digitalWrite(CE_bar, CE_disable);
  delay(20);
  setAddress(address);
  for (int pin = EPROM_D0; pin <= EPROM_D7; pin += 1) {
    pinMode(pin, OUTPUT);
  }

  for (int pin = EPROM_D0; pin <= EPROM_D7; pin += 1) {
    digitalWrite(pin, data & 1);
    data = data >> 1;
  }

  //envoyer 12.5v dans OE pour ecriture
  digitalWrite(CMD_OE_BAR_0V, LOW);
  digitalWrite(CMD_OE_BAR_12V_5V, HIGH);

  digitalWrite(CE_bar, CE_enable);
  delayMicroseconds(1);
  digitalWrite(CE_bar, CE_disable);
  delay(10);

  digitalWrite(CMD_ALIM_EPROM_5V_6V, HIGH);//alim 5v
  delay(10);
}

/*
 * Read the contents of the EEPROM and print them to the serial monitor.
 */
void printContents() {
  Serial.println("\r\n-----------------------------------\r\n");

  for (int base = 0; base <= MEMORY_SIZE-1; base += 16) {
    byte data[16];
    for (int offset = 0; offset <= 15; offset += 1) {
      data[offset] = readEPROM(base + offset);
    }

    char buf[80];
    sprintf(buf, "%03x:  %02x %02x %02x %02x %02x %02x %02x %02x   %02x %02x %02x %02x %02x %02x %02x %02x",
            base, data[0], data[1], data[2], data[3], data[4], data[5], data[6], data[7],
            data[8], data[9], data[10], data[11], data[12], data[13], data[14], data[15]);

    Serial.println(buf);
  }
}

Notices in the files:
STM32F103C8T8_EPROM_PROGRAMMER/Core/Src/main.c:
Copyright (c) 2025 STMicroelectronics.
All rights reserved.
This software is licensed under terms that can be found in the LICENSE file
